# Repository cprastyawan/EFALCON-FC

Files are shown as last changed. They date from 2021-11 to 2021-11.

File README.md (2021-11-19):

# EFALCON-FC

Flight Controller Prototype for X type Quadcopter
Components:
1. STM32F407VGT6 Dev EBox as Microcontroller
2. GY-91: MPU9250 & BMP280 as Sensors
3. Receiver Radio Remote Control (SBUS/PPM/PWM) as Input

Programmings:
1. STM32CubeIDE as IDE
2. STM32 HAL Library as main library
3. CMSIS OS Platform for Real Time Operating System (RTOS)

need info?
ig: CPrastyawan

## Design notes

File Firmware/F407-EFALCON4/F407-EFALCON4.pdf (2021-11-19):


24/06/2021

## F407-EFALCON4 Project Configuration Report

# 1. Description

## 1.1. Project

Project Name | F407-EFALCON4
Board Name | custom
Generated with: | STM32CubeMX 6.2.1
Date | 06/24/2021

## 1.2. MCU

MCU Series | STM32F4
MCU Line | STM32F407/417
MCU name | STM32F407VGTx
MCU Package | LQFP100
MCU Pin number | 100

## 1.3. Core(s) information

Core(s) | Arm Cortex-M4

# 2. Pinout Configuration

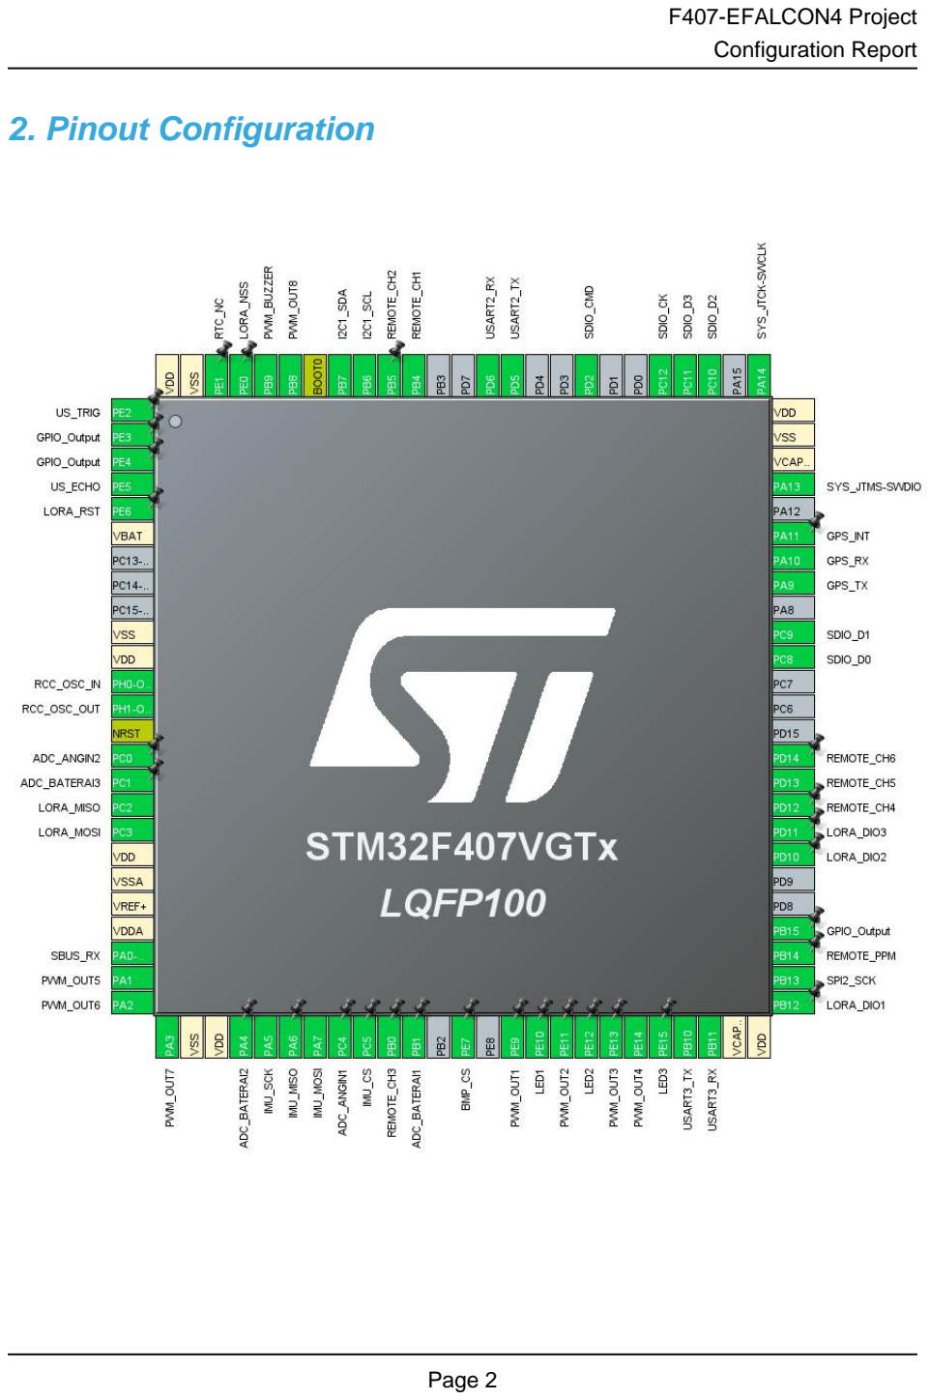
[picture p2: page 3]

# 3. Pins Configuration

Pin Number LQFP100 | Pin Name (function after reset) | Pin Type | Alternate Function(s) | Label
1 | PE2 * | I/O | GPIO_Output | US_TRIG
2 | PE3 * | I/O | GPIO_Output
3 | PE4 * | I/O | GPIO_Output
4 | PE5 | I/O | TIM9_CH1 | US_ECHO
5 | PE6 * | I/O | GPIO_Output | LORA_RST
6 | VBAT | Power
10 | VSS | Power
11 | VDD | Power
12 | PH0-OSC_IN | I/O | RCC_OSC_IN
13 | PH1-OSC_OUT | I/O | RCC_OSC_OUT
14 | NRST | Reset
15 | PC0 | I/O | ADC1_IN10 | ADC_ANGIN2
16 | PC1 | I/O | ADC1_IN11 | ADC_BATERAI3
17 | PC2 | I/O | SPI2_MISO | LORA_MISO
18 | PC3 | I/O | SPI2_MOSI | LORA_MOSI
19 | VDD | Power
20 | VSSA | Power
21 | VREF+ | Power
22 | VDDA | Power
23 | PA0-WKUP | I/O | UART4_TX | SBUS_RX
24 | PA1 | I/O | TIM5_CH2 | PWM_OUT5
25 | PA2 | I/O | TIM5_CH3 | PWM_OUT6
26 | PA3 | I/O | TIM5_CH4 | PWM_OUT7
27 | VSS | Power
28 | VDD | Power
29 | PA4 | I/O | ADC1_IN4 | ADC_BATERAI2
30 | PA5 | I/O | SPI1_SCK | IMU_SCK
31 | PA6 | I/O | SPI1_MISO | IMU_MISO
32 | PA7 | I/O | SPI1_MOSI | IMU_MOSI
33 | PC4 | I/O | ADC1_IN14 | ADC_ANGIN1
34 | PC5 * | I/O | GPIO_Output | IMU_CS
35 | PB0 | I/O | TIM3_CH3 | REMOTE_CH3
36 | PB1 | I/O | ADC1_IN9 | ADC_BATERAI1
38 | PE7 * | I/O | GPIO_Output | BMP_CS
40 | PE9 | I/O | TIM1_CH1 | PWM_OUT1
41 | PE10 * | I/O | GPIO_Output | LED1

Pin Number LQFP100 | Pin Name (function after reset) | Pin Type | Alternate Function(s) | Label
42 | PE11 | I/O | TIM1_CH2 | PWM_OUT2
43 | PE12 * | I/O | GPIO_Output | LED2
44 | PE13 | I/O | TIM1_CH3 | PWM_OUT3
45 | PE14 | I/O | TIM1_CH4 | PWM_OUT4
46 | PE15 * | I/O | GPIO_Output | LED3
47 | PB10 | I/O | USART3_TX
48 | PB11 | I/O | USART3_RX
49 | VCAP_1 | Power
50 | VDD | Power
51 | PB12 * | I/O | GPIO_Output | LORA_DIO1
52 | PB13 | I/O | SPI2_SCK
53 | PB14 | I/O | TIM12_CH1 | REMOTE_PPM
54 | PB15 * | I/O | GPIO_Output
57 | PD10 * | I/O | GPIO_Output | LORA_DIO2
58 | PD11 * | I/O | GPIO_Output | LORA_DIO3
59 | PD12 | I/O | TIM4_CH1 | REMOTE_CH4
60 | PD13 | I/O | TIM4_CH2 | REMOTE_CH5
61 | PD14 | I/O | TIM4_CH3 | REMOTE_CH6
65 | PC8 | I/O | SDIO_D0
66 | PC9 | I/O | SDIO_D1
68 | PA9 | I/O | USART1_TX | GPS_TX
69 | PA10 | I/O | USART1_RX | GPS_RX
70 | PA11 | I/O | GPIO_EXTI11 | GPS_INT
72 | PA13 | I/O | SYS_JTMS-SWDIO
73 | VCAP_2 | Power
74 | VSS | Power
75 | VDD | Power
76 | PA14 | I/O | SYS_JTCK-SWCLK
78 | PC10 | I/O | SDIO_D2
79 | PC11 | I/O | SDIO_D3
80 | PC12 | I/O | SDIO_CK
83 | PD2 | I/O | SDIO_CMD
86 | PD5 | I/O | USART2_TX
87 | PD6 | I/O | USART2_RX
90 | PB4 | I/O | TIM3_CH1 | REMOTE_CH1
91 | PB5 | I/O | TIM3_CH2 | REMOTE_CH2
92 | PB6 | I/O | I2C1_SCL
93 | PB7 | I/O | I2C1_SDA
94 | BOOT0 | Boot

Pin Number LQFP100 | Pin Name (function after reset) | Pin Type | Alternate Function(s) | Label
95 | PB8 | I/O | TIM10_CH1 | PWM_OUT8
96 | PB9 | I/O | TIM11_CH1 | PWM_BUZZER
97 | PE0 * | I/O | GPIO_Output | LORA_NSS
98 | PE1 * | I/O | GPIO_Output | RTC_NC
99 | VSS | Power
100 | VDD | Power

## * The pin is affected with an I/O function

# 4. Clock Tree Configuration

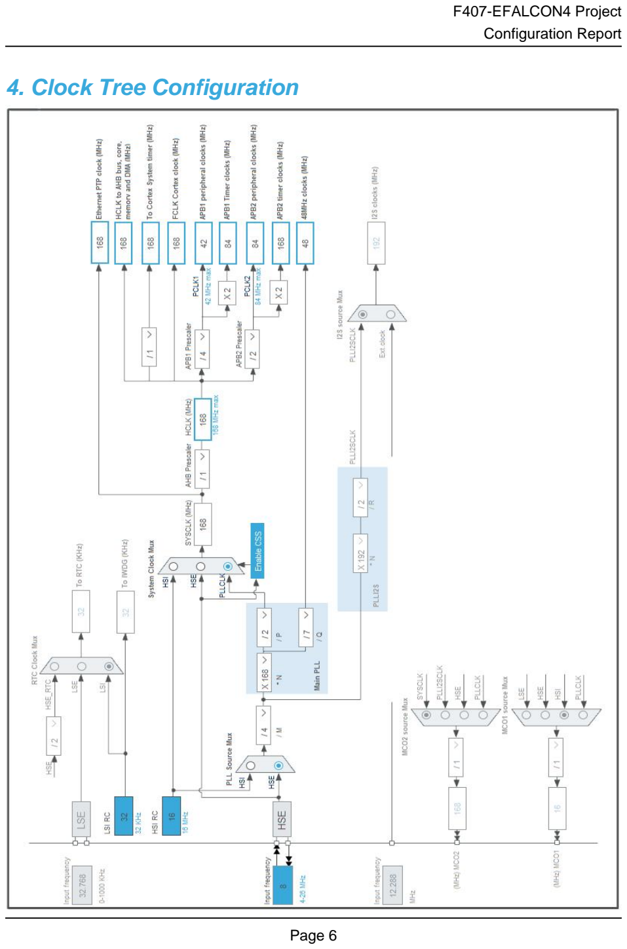
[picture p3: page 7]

# 5. Software Project

## 5.1. Project Settings

Name | Value
Project Name | F407-EFALCON4
Project Folder | C:\Users\LENOVO\git\F407-EFALCON4\F407-EFALCON4
Toolchain / IDE | STM32CubeIDE
Firmware Package Name and Version | STM32Cube FW_F4 V1.26.1
Application Structure | Advanced
Generate Under Root | Yes
Do not generate the main() | No
Minimum Heap Size | 0x200
Minimum Stack Size | 0x400

## 5.2. Code Generation Settings

Name | Value
STM32Cube MCU packages and embedded software | Copy only the necessary library files
Generate peripheral initialization as a pair of '.c/.h' files | No
Backup previously generated files when re-generating | No
Keep User Code when re-generating | Yes
Delete previously generated files when not re-generated | Yes
Set all free pins as analog (to optimize the power consumption) | No
Enable Full Assert | No

## 5.3. Advanced Settings - Generated Function Calls

Rank | Function Name | Peripheral Instance Name
1 | MX_GPIO_Init | GPIO
2 | SystemClock_Config | RCC
3 | MX_I2C1_Init | I2C1
4 | MX_SDIO_SD_Init | SDIO
5 | MX_SPI1_Init | SPI1
6 | MX_SPI2_Init | SPI2
7 | MX_TIM5_Init | TIM5
8 | MX_TIM9_Init | TIM9
9 | MX_TIM10_Init | TIM10
10 | MX_TIM11_Init | TIM11
11 | MX_UART4_Init | UART4

Rank | Function Name | Peripheral Instance Name
12 | MX_USART1_UART_Init | USART1
13 | MX_USART2_UART_Init | USART2
14 | MX_USART3_UART_Init | USART3
15 | MX_ADC1_Init | ADC1
16 | MX_TIM2_Init | TIM2
17 | MX_TIM6_Init | TIM6
18 | MX_TIM12_Init | TIM12
19 | MX_FATFS_Init | FATFS
20 | MX_TIM1_Init | TIM1
21 | MX_TIM3_Init | TIM3
22 | MX_TIM4_Init | TIM4

# 6. Power Consumption Calculator report

## 6.1. Microcontroller Selection

Series | STM32F4
Line | STM32F407/417
MCU | STM32F407VGTx
Datasheet | DS8626_Rev8

## 6.2. Parameter Selection

Temperature | 25
Vdd | 3.3

## 6.3. Battery Selection

Battery | Li-SOCL2(A3400)
Capacity | 3400.0 mAh
Self Discharge | 0.08 %/month
Nominal Voltage | 3.6 V
Max Cont Current | 100.0 mA
Max Pulse Current | 200.0 mA
Cells in series | 1
Cells in parallel | 1

## 6.4. Sequence

Step | Step1 | Step2
Mode | RUN | STOP
Vdd | 3.3 | 3.3
Voltage Source | Battery | Battery
Range | Scale1-High | No Scale
Fetch Type | FLASH | n/a
CPU Frequency | 168 MHz | 0 Hz
Clock Configuration | HSE PLL | Regulator_LP Flash-PwrDwn
Clock Source Frequency | 4 MHz | 0 Hz

### Peripherals

Additional Cons. | 0 mA | 0 mA
Average Current | 46 mA | 280 µA
Duration | 0.1 ms | 0.9 ms
DMIPS | 210.0 | 0.0
Ta Max | 98.47 | 104.96
Category | In DS Table | In DS Table

## 6.5. Results

Sequence Time | 1 ms | Average Current | 4.85 mA
Battery Life | 29 days, 4 hours | Average DMIPS | 210.0 DMIPS

## 6.6. Chart

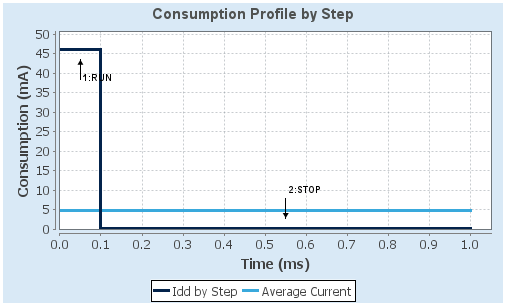
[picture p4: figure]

# 7. Peripherals and Middlewares Configuration

## 7.1. ADC1 mode: IN4 mode: IN9 mode: IN10 mode: IN11 mode: IN14

## 7.1.1. Parameter Settings:

### ADCs_Common_Settings:

Mode | Independent mode

### ADC_Settings:

Clock Prescaler | PCLK2 divided by 4
Resolution | 12 bits (15 ADC Clock cycles)
Data Alignment | Right alignment
Scan Conversion Mode | Disabled
Continuous Conversion Mode | Disabled
Discontinuous Conversion Mode | Disabled
DMA Continuous Requests | Disabled
End Of Conversion Selection | EOC flag at the end of single channel conversion

### ADC_Regular_ConversionMode:

Number Of Conversion | 1
External Trigger Conversion Source | Regular Conversion launched by software
External Trigger Conversion Edge | None
Rank | 1
Channel | Channel 9 *
Sampling Time | 3 Cycles

### ADC_Injected_ConversionMode:

Number Of Conversions | 0

### WatchDog:

Enable Analog WatchDog Mode | false

## 7.2. I2C1 I2C: I2C

## 7.2.1. Parameter Settings:

### Master Features:

I2C Speed Mode | Standard Mode
I2C Clock Speed (Hz) | 100000

### Slave Features:

Clock No Stretch Mode | Disabled
Primary Address Length selection | 7-bit
Dual Address Acknowledged | Disabled
Primary slave address | 0
General Call address detection | Disabled

## 7.3. RCC High Speed Clock (HSE): Crystal/Ceramic Resonator

## 7.3.1. Parameter Settings:

### System Parameters:

VDD voltage (V) | 3.3
Instruction Cache | Enabled
Prefetch Buffer | Enabled
Data Cache | Enabled
Flash Latency(WS) | 5 WS (6 CPU cycle)

### RCC Parameters:

HSI Calibration Value | 16
HSE Startup Timout Value (ms) | 100
LSE Startup Timout Value (ms) | 5000

### Power Parameters:

Power Regulator Voltage Scale | Power Regulator Voltage Scale 1

## 7.4. SDIO Mode: SD 4 bits Wide bus

## 7.4.1. Parameter Settings:

### SDIO parameters:

Clock transition on which the bit capture is made | Rising transition
SDIO Clock divider bypass | Disable
SDIO Clock output enable when the bus is idle | Disable the power save for the clock
SDIO hardware flow control | The hardware control flow is disabled
SDIOCLK clock divide factor | 4 *

## 7.5. SPI1 Mode: Full-Duplex Master

## 7.5.1. Parameter Settings:

### Basic Parameters:

Frame Format | Motorola
Data Size | 8 Bits
First Bit | MSB First

### Clock Parameters:

Prescaler (for Baud Rate) | 32 *
Baud Rate | 2.625 MBits/s *
Clock Polarity (CPOL) | Low
Clock Phase (CPHA) | 1 Edge

### Advanced Parameters:

CRC Calculation | Disabled
NSS Signal Type | Software

## 7.6. SPI2 Mode: Full-Duplex Master

## 7.6.1. Parameter Settings:

### Basic Parameters:

Frame Format | Motorola
Data Size | 8 Bits
First Bit | MSB First

### Clock Parameters:

Prescaler (for Baud Rate) | 2
Baud Rate | 21.0 MBits/s *
Clock Polarity (CPOL) | Low
Clock Phase (CPHA) | 1 Edge

### Advanced Parameters:

CRC Calculation | Disabled
NSS Signal Type | Software

## 7.7. SYS Debug: Serial Wire Timebase Source: TIM7

## 7.8. TIM1 Channel1: PWM Generation CH1 Channel2: PWM Generation CH2 Channel3: PWM Generation CH3 Channel4: PWM Generation CH4

## 7.8.1. Parameter Settings:

### Counter Settings:

Prescaler (PSC - 16 bits value) | 0
Counter Mode | Up
Counter Period (AutoReload Register - 16 bits value ) | 65535
Internal Clock Division (CKD) | No Division
Repetition Counter (RCR - 8 bits value) | 0
auto-reload preload | Disable

### Trigger Output (TRGO) Parameters:

Master/Slave Mode (MSM bit) | Disable (Trigger input effect not delayed)
Trigger Event Selection | Reset (UG bit from TIMx_EGR)

### Break And Dead Time management - BRK Configuration:

BRK State | Disable
BRK Polarity | High

### Break And Dead Time management - Output Configuration:

Automatic Output State | Disable
Off State Selection for Run Mode (OSSR) | Disable
Off State Selection for Idle Mode (OSSI) | Disable
Lock Configuration | Off

### PWM Generation Channel 1:

Mode | PWM mode 1
Pulse (16 bits value) | 0
Output compare preload | Enable
Fast Mode | Disable
CH Polarity | High
CH Idle State | Reset

### PWM Generation Channel 2:

Mode | PWM mode 1

Pulse (16 bits value) | 0
Output compare preload | Enable
Fast Mode | Disable
CH Polarity | High
CH Idle State | Reset

### PWM Generation Channel 3:

Mode | PWM mode 1
Pulse (16 bits value) | 0
Output compare preload | Enable
Fast Mode | Disable
CH Polarity | High
CH Idle State | Reset

### PWM Generation Channel 4:

Mode | PWM mode 1
Pulse (16 bits value) | 0
Output compare preload | Enable
Fast Mode | Disable
CH Polarity | High
CH Idle State | Reset

## 7.9. TIM2 Clock Source : Internal Clock

## 7.9.1. Parameter Settings:

### Counter Settings:

Prescaler (PSC - 16 bits value) | 0
Counter Mode | Up
Counter Period (AutoReload Register - 32 bits value ) | 4294967295
Internal Clock Division (CKD) | No Division
auto-reload preload | Disable

### Trigger Output (TRGO) Parameters:

Master/Slave Mode (MSM bit) | Disable (Trigger input effect not delayed)
Trigger Event Selection | Reset (UG bit from TIMx_EGR)

## 7.10. TIM3 Channel1: Input Capture direct mode Channel2: Input Capture direct mode

## Channel3: Input Capture direct mode

## 7.10.1. Parameter Settings:

### Counter Settings:

Prescaler (PSC - 16 bits value) | 0
Counter Mode | Up
Counter Period (AutoReload Register - 16 bits value ) | 65535
Internal Clock Division (CKD) | No Division
auto-reload preload | Disable

### Trigger Output (TRGO) Parameters:

Master/Slave Mode (MSM bit) | Disable (Trigger input effect not delayed)
Trigger Event Selection | Reset (UG bit from TIMx_EGR)

### Input Capture Channel 1:

Polarity Selection | Rising Edge
IC Selection | Direct
Prescaler Division Ratio | No division
Input Filter (4 bits value) | 0

### Input Capture Channel 2:

Polarity Selection | Rising Edge
IC Selection | Direct
Prescaler Division Ratio | No division
Input Filter (4 bits value) | 0

### Input Capture Channel 3:

Polarity Selection | Rising Edge
IC Selection | Direct
Prescaler Division Ratio | No division
Input Filter (4 bits value) | 0

## 7.11. TIM4 Channel1: Input Capture direct mode Channel2: Input Capture direct mode Channel3: Input Capture direct mode

## 7.11.1. Parameter Settings:

### Counter Settings:

Prescaler (PSC - 16 bits value) | 0
Counter Mode | Up
Counter Period (AutoReload Register - 16 bits value ) | 65535
Internal Clock Division (CKD) | No Division

auto-reload preload | Disable

### Trigger Output (TRGO) Parameters:

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

### Input Capture Channel 1:

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

### Input Capture Channel 2:

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

### Input Capture Channel 3:

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

## 7.12. TIM5 Channel2: PWM Generation CH2 Channel3: PWM Generation CH3 Channel4: PWM Generation CH4

## 7.12.1. Parameter Settings:

### Counter Settings:

Prescaler (PSC - 16 bits value) | 0
Counter Mode | Up
Counter Period (AutoReload Register - 32 bits value ) | 4294967295
Internal Clock Division (CKD) | No Division
auto-reload preload | Disable

### Trigger Output (TRGO) Parameters:

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

### PWM Generation Channel 2:

Mode | PWM mode 1
Pulse (32 bits value) | 0
Output compare preload | Enable

Fast Mode | Disable
CH Polarity | High

### PWM Generation Channel 3:

Mode | PWM mode 1
Pulse (32 bits value) | 0
Output compare preload | Enable
Fast Mode | Disable
CH Polarity | High

### PWM Generation Channel 4:

Mode | PWM mode 1
Pulse (32 bits value) | 0
Output compare preload | Enable
Fast Mode | Disable
CH Polarity | High

## 7.13. TIM6 mode: Activated

## 7.13.1. Parameter Settings:

### Counter Settings:

Prescaler (PSC - 16 bits value) | 84 - 1 *
Counter Mode | Up
Counter Period (AutoReload Register - 16 bits value ) | 10 - 1 *
auto-reload preload | Disable

### Trigger Output (TRGO) Parameters:

Trigger Event Selection | Reset (UG bit from TIMx_EGR)

## 7.14. TIM9 Channel1: Input Capture direct mode Channel2: Input Capture indirect mode

## 7.14.1. Parameter Settings:

### Counter Settings:

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

auto-reload preload | Disable

### Input Capture Channel 1:

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

### Input Capture Channel 2:

Polarity Selection | Rising Edge
IC Selection | Indirect
Prescaler Division Ratio | No division

## 7.15. TIM10 mode: Activated Channel1: PWM Generation CH1

## 7.15.1. Parameter Settings:

### Counter Settings:

Prescaler (PSC - 16 bits value) | 0
Counter Mode | Up
Counter Period (AutoReload Register - 16 bits value ) | 65535
Internal Clock Division (CKD) | No Division
auto-reload preload | Disable

### PWM Generation Channel 1:

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

## 7.16. TIM11 mode: Activated Channel1: PWM Generation CH1

## 7.16.1. Parameter Settings:

### Counter Settings:

Prescaler (PSC - 16 bits value) | 0
Counter Mode | Up

Counter Period (AutoReload Register - 16 bits value ) | 65535
Internal Clock Division (CKD) | No Division
auto-reload preload | Disable

### PWM Generation Channel 1:

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

## 7.17. TIM12 Channel1: Input Capture direct mode Channel2: Input Capture indirect mode

## 7.17.1. Parameter Settings:

### Counter Settings:

Prescaler (PSC - 16 bits value) | 84 - 1 *
Counter Mode | Up
Counter Period (AutoReload Register - 16 bits value ) | 65535
Internal Clock Division (CKD) | No Division
auto-reload preload | Disable

### Input Capture Channel 1:

Polarity Selection | Falling Edge *
IC Selection | Direct
Prescaler Division Ratio | No division
Input Filter (4 bits value) | 0

### Input Capture Channel 2:

Polarity Selection | Rising Edge
IC Selection | Indirect
Prescaler Division Ratio | No division

## 7.18. UART4 Mode: Single Wire (Half-Duplex)

## 7.18.1. Parameter Settings:

### Basic Parameters:

Baud Rate | 115200

Word Length | 8 Bits (including Parity)
Parity | None
Stop Bits | 1

### Advanced Parameters:

Data Direction | Receive Only *
Over Sampling | 16 Samples

## 7.19. USART1 Mode: Asynchronous

## 7.19.1. Parameter Settings:

### Basic Parameters:

Baud Rate | 115200
Word Length | 8 Bits (including Parity)
Parity | None
Stop Bits | 1

### Advanced Parameters:

Data Direction | Receive and Transmit
Over Sampling | 16 Samples

## 7.20. USART2 Mode: Asynchronous

## 7.20.1. Parameter Settings:

### Basic Parameters:

Baud Rate | 115200
Word Length | 8 Bits (including Parity)
Parity | None
Stop Bits | 1

### Advanced Parameters:

Data Direction | Receive and Transmit
Over Sampling | 16 Samples

## 7.21. USART3

## Mode: Asynchronous

## 7.21.1. Parameter Settings:

### Basic Parameters:

Baud Rate | 115200
Word Length | 8 Bits (including Parity)
Parity | None
Stop Bits | 1

### Advanced Parameters:

Data Direction | Receive and Transmit
Over Sampling | 16 Samples

## 7.22. ARM.CMSIS.5.6.0 mode: CMSISJjDSP

## 7.23. FATFS mode: SD Card

## 7.23.1. Set Defines:

### Version:

FATFS version | R0.12c

### Function Parameters:

FS_READONLY (Read-only mode) | Disabled
FS_MINIMIZE (Minimization level) | Disabled
USE_STRFUNC (String functions) | Enabled with LF -> CRLF conversion
USE_FIND (Find functions) | Disabled
USE_MKFS (Make filesystem function) | Enabled
USE_FASTSEEK (Fast seek function) | Enabled
USE_EXPAND (Use f_expand function) | Disabled
USE_CHMOD (Change attributes function) | Disabled
USE_LABEL (Volume label functions) | Disabled
USE_FORWARD (Forward function) | Disabled

### Locale and Namespace Parameters:

CODE_PAGE (Code page on target) | Latin 1
USE_LFN (Use Long Filename) | Disabled
MAX_LFN (Max Long Filename) | 255
LFN_UNICODE (Enable Unicode) | ANSI/OEM
STRF_ENCODE (Character encoding) | UTF-8
FS_RPATH (Relative Path) | Disabled

### Physical Drive Parameters:

VOLUMES (Logical drives) | 1
MAX_SS (Maximum Sector Size) | 512
MIN_SS (Minimum Sector Size) | 512
MULTI_PARTITION (Volume partitions feature) | Disabled
USE_TRIM (Erase feature) | Disabled
FS_NOFSINFO (Force full FAT scan) | 0

### System Parameters:

FS_TINY (Tiny mode) | Disabled
FS_EXFAT (Support of exFAT file system) | Disabled
FS_NORTC (Timestamp feature) | Dynamic timestamp
FS_REENTRANT (Re-Entrancy) | Enabled
FS_TIMEOUT (Timeout ticks) | 1000
USE_MUTEX | Disabled
SYNC_t (O/S sync object) | osSemaphoreId_t
FS_LOCK (Number of files opened simultaneously) | 2

## 7.23.2. Advanced Settings:

### SDIO/SDMMC:

SDIO instance | SDIO
Use dma template | Enabled
BSP code for SD | Generic

## 7.24. FREERTOS Interface: CMSIS_V2

## 7.24.1. Config parameters:

### API:

FreeRTOS API | CMSIS v2

### Versions:

FreeRTOS version | 10.3.1
CMSIS-RTOS version | 2.00

### MPU/FPU:

ENABLE_MPU | Disabled
ENABLE_FPU | Enabled *

### Kernel settings:

USE_PREEMPTION | Enabled
CPU_CLOCK_HZ | SystemCoreClock

TICK_RATE_HZ | 1000
MAX_PRIORITIES | 56
MINIMAL_STACK_SIZE | 512 *
MAX_TASK_NAME_LEN | 16
USE_16_BIT_TICKS | Disabled
IDLE_SHOULD_YIELD | Enabled
USE_MUTEXES | Enabled
USE_RECURSIVE_MUTEXES | Enabled
USE_COUNTING_SEMAPHORES | Enabled
QUEUE_REGISTRY_SIZE | 8
USE_APPLICATION_TASK_TAG | Disabled
ENABLE_BACKWARD_COMPATIBILITY | Enabled
USE_PORT_OPTIMISED_TASK_SELECTION | Disabled
USE_TICKLESS_IDLE | Disabled
USE_TASK_NOTIFICATIONS | Enabled
RECORD_STACK_HIGH_ADDRESS | Disabled

### Memory management settings:

Memory Allocation | Dynamic / Static
TOTAL_HEAP_SIZE | 15360
Memory Management scheme | heap_4

### Hook function related definitions:

USE_IDLE_HOOK | Disabled
USE_TICK_HOOK | Disabled
USE_MALLOC_FAILED_HOOK | Disabled
USE_DAEMON_TASK_STARTUP_HOOK | Disabled
CHECK_FOR_STACK_OVERFLOW | Disabled

### Run time and task stats gathering related definitions:

GENERATE_RUN_TIME_STATS | Disabled
USE_TRACE_FACILITY | Enabled
USE_STATS_FORMATTING_FUNCTIONS | Disabled

### Co-routine related definitions:

USE_CO_ROUTINES | Disabled
MAX_CO_ROUTINE_PRIORITIES | 2

### Software timer definitions:

USE_TIMERS | Enabled
TIMER_TASK_PRIORITY | 2
TIMER_QUEUE_LENGTH | 10
TIMER_TASK_STACK_DEPTH | 1024

### Interrupt nesting behaviour configuration:

LIBRARY_LOWEST_INTERRUPT_PRIORITY | 15
LIBRARY_MAX_SYSCALL_INTERRUPT_PRIORITY | 5

### Added with 10.2.1 support:

MESSAGE_BUFFER_LENGTH_TYPE | size_t
USE_POSIX_ERRNO | Disabled

### CMSIS-RTOS V2 flags:

USE_OS2_THREAD_SUSPEND_RESUME | Enabled
USE_OS2_THREAD_ENUMERATE | Enabled
USE_OS2_EVENTFLAGS_FROM_ISR | Enabled
USE_OS2_THREAD_FLAGS | Enabled
USE_OS2_TIMER | Enabled
USE_OS2_MUTEX | Enabled

## 7.24.2. Include parameters:

### Include definitions:

vTaskPrioritySet | Enabled
uxTaskPriorityGet | Enabled
vTaskDelete | Enabled
vTaskCleanUpResources | Disabled
vTaskSuspend | Enabled
vTaskDelayUntil | Enabled
vTaskDelay | Enabled
xTaskGetSchedulerState | Enabled
xTaskResumeFromISR | Enabled
xQueueGetMutexHolder | Enabled
xSemaphoreGetMutexHolder | Disabled
pcTaskGetTaskName | Disabled
uxTaskGetStackHighWaterMark | Enabled
xTaskGetCurrentTaskHandle | Enabled
eTaskGetState | Enabled
xEventGroupSetBitFromISR | Disabled
xTimerPendFunctionCall | Enabled
xTaskAbortDelay | Disabled
xTaskGetHandle | Disabled
uxTaskGetStackHighWaterMark2 | Disabled

## 7.24.3. Advanced settings:

### Newlib settings (see parameter description first):

USE_NEWLIB_REENTRANT | Disabled

### Project settings (see parameter description first):

Use FW pack heap file | Enabled

### * User modified value

# 8. System Configuration

## 8.1. GPIO configuration

IP | Pin | Signal | GPIO mode | GPIO pull/up pull down

## Max Speed

## User Label

ADC1 | PC0 | ADC1_IN10 | Analog mode | No pull-up and no pull-down | n/a | ADC_ANGIN2
| PC1 | ADC1_IN11 | Analog mode | No pull-up and no pull-down | n/a | ADC_BATERAI3
| PA4 | ADC1_IN4 | Analog mode | No pull-up and no pull-down | n/a | ADC_BATERAI2
| PC4 | ADC1_IN14 | Analog mode | No pull-up and no pull-down | n/a | ADC_ANGIN1
| PB1 | ADC1_IN9 | Analog mode | No pull-up and no pull-down | n/a | ADC_BATERAI1
I2C1 | PB6 | I2C1_SCL | Alternate Function Open Drain | Pull-up | Very High
*
| PB7 | I2C1_SDA | Alternate Function Open Drain | Pull-up | Very High
*
RCC | PH0- OSC_IN | RCC_OSC_IN | n/a | n/a | n/a
| PH1- OSC_OUT | RCC_OSC_OUT | n/a | n/a | n/a
SDIO | PC8 | SDIO_D0 | Alternate Function Push Pull | No pull-up and no pull-down | Very High
| PC9 | SDIO_D1 | Alternate Function Push Pull | No pull-up and no pull-down | Very High
| PC10 | SDIO_D2 | Alternate Function Push Pull | No pull-up and no pull-down | Very High
| PC11 | SDIO_D3 | Alternate Function Push Pull | No pull-up and no pull-down | Very High
| PC12 | SDIO_CK | Alternate Function Push Pull | No pull-up and no pull-down | Very High
| PD2 | SDIO_CMD | Alternate Function Push Pull | No pull-up and no pull-down | Very High
SPI1 | PA5 | SPI1_SCK | Alternate Function Push Pull | No pull-up and no pull-down | Very High
*
| | | | | | IMU_SCK
| PA6 | SPI1_MISO | Alternate Function Push Pull | No pull-up and no pull-down | Very High
*
| | | | | | IMU_MISO
| PA7 | SPI1_MOSI | Alternate Function Push Pull | No pull-up and no pull-down | Very High
*
| | | | | | IMU_MOSI
SPI2 | PC2 | SPI2_MISO | Alternate Function Push Pull | No pull-up and no pull-down | Very High
*
| | | | | | LORA_MISO
| PC3 | SPI2_MOSI | Alternate Function Push Pull | No pull-up and no pull-down | Very High
*
| | | | | | LORA_MOSI
| PB13 | SPI2_SCK | Alternate Function Push Pull | No pull-up and no pull-down | Very High
*
SYS | PA13 | SYS_JTMS- SWDIO | n/a | n/a | n/a
| PA14 | SYS_JTCK- SWCLK | n/a | n/a | n/a

IP | Pin | Signal | GPIO mode | GPIO pull/up pull down

## Max Speed

## User Label

TIM1 | PE9 | TIM1_CH1 | Alternate Function Push Pull | No pull-up and no pull-down | Low | PWM_OUT1
| PE11 | TIM1_CH2 | Alternate Function Push Pull | No pull-up and no pull-down | Low | PWM_OUT2
| PE13 | TIM1_CH3 | Alternate Function Push Pull | No pull-up and no pull-down | Low | PWM_OUT3
| PE14 | TIM1_CH4 | Alternate Function Push Pull | No pull-up and no pull-down | Low | PWM_OUT4
TIM3 | PB0 | TIM3_CH3 | Alternate Function Push Pull | No pull-up and no pull-down | Low | REMOTE_CH3
| PB4 | TIM3_CH1 | Alternate Function Push Pull | No pull-up and no pull-down | Low | REMOTE_CH1
| PB5 | TIM3_CH2 | Alternate Function Push Pull | No pull-up and no pull-down | Low | REMOTE_CH2
TIM4 | PD12 | TIM4_CH1 | Alternate Function Push Pull | No pull-up and no pull-down | Low | REMOTE_CH4
| PD13 | TIM4_CH2 | Alternate Function Push Pull | No pull-up and no pull-down | Low | REMOTE_CH5
| PD14 | TIM4_CH3 | Alternate Function Push Pull | No pull-up and no pull-down | Low | REMOTE_CH6
TIM5 | PA1 | TIM5_CH2 | Alternate Function Push Pull | No pull-up and no pull-down | Low | PWM_OUT5
| PA2 | TIM5_CH3 | Alternate Function Push Pull | No pull-up and no pull-down | Low | PWM_OUT6
| PA3 | TIM5_CH4 | Alternate Function Push Pull | No pull-up and no pull-down | Low | PWM_OUT7
TIM9 | PE5 | TIM9_CH1 | Alternate Function Push Pull | No pull-up and no pull-down | Low | US_ECHO
TIM10 | PB8 | TIM10_CH1 | Alternate Function Push Pull | No pull-up and no pull-down | Low | PWM_OUT8
TIM11 | PB9 | TIM11_CH1 | Alternate Function Push Pull | No pull-up and no pull-down | Low | PWM_BUZZER
TIM12 | PB14 | TIM12_CH1 | Alternate Function Push Pull | No pull-up and no pull-down | Low | REMOTE_PPM
UART4 | PA0-WKUP | UART4_TX | Alternate Function Open Drain | Pull-up | Very High
*
| | | | | | SBUS_RX
USART1 | PA9 | USART1_TX | Alternate Function Push Pull | No pull-up and no pull-down | Very High
*
| | | | | | GPS_TX
| PA10 | USART1_RX | Alternate Function Push Pull | No pull-up and no pull-down | Very High
*
| | | | | | GPS_RX
USART2 | PD5 | USART2_TX | Alternate Function Push Pull | No pull-up and no pull-down | Very High
*
| PD6 | USART2_RX | Alternate Function Push Pull | No pull-up and no pull-down | Very High
*
USART3 | PB10 | USART3_TX | Alternate Function Push Pull | No pull-up and no pull-down | Very High
*
| PB11 | USART3_RX | Alternate Function Push Pull | No pull-up and no pull-down | Very High
*
GPIO | PE2 | GPIO_Output | Output Push Pull | No pull-up and no pull-down | Low | US_TRIG
| PE3 | GPIO_Output | Output Push Pull | No pull-up and no pull-down | Low
| PE4 | GPIO_Output | Output Push Pull | No pull-up and no pull-down | Low
| PE6 | GPIO_Output | Output Push Pull | No pull-up and no pull-down | Low | LORA_RST
| PC5 | GPIO_Output | Output Push Pull | No pull-up and no pull-down | Low | IMU_CS
| PE7 | GPIO_Output | Output Push Pull | No pull-up and no pull-down | Low | BMP_CS
| PE10 | GPIO_Output | Output Push Pull | No pull-up and no pull-down | Low | LED1
| PE12 | GPIO_Output | Output Push Pull | No pull-up and no pull-down | Low | LED2

IP | Pin | Signal | GPIO mode | GPIO pull/up pull down | Max Speed | User Label
| PE15 | GPIO_Output | Output Push Pull | No pull-up and no pull-down | Low | LED3
| PB12 | GPIO_Output | Output Push Pull | No pull-up and no pull-down | Low | LORA_DIO1
| PB15 | GPIO_Output | Output Push Pull | No pull-up and no pull-down | Low
| PD10 | GPIO_Output | Output Push Pull | No pull-up and no pull-down | Low | LORA_DIO2
| PD11 | GPIO_Output | Output Push Pull | No pull-up and no pull-down | Low | LORA_DIO3
| PA11 | GPIO_EXTI11 | External Interrupt Mode with Rising edge trigger detection | No pull-up and no pull-down | n/a | GPS_INT
| PE0 | GPIO_Output | Output Push Pull | No pull-up and no pull-down | Low | LORA_NSS
| PE1 | GPIO_Output | Output Push Pull | No pull-up and no pull-down | Low | RTC_NC

## 8.2. DMA configuration

## nothing configured in DMA service

## 8.3. NVIC configuration

## 8.3.1. NVIC

Interrupt Table | Enable | Preenmption Priority | SubPriority
Non maskable interrupt | true | 0 | 0
Hard fault interrupt | true | 0 | 0
Memory management fault | true | 0 | 0
Pre-fetch fault, memory access fault | true | 0 | 0
Undefined instruction or illegal state | true | 0 | 0
System service call via SWI instruction | true | 0 | 0
Debug monitor | true | 0 | 0
Pendable request for system service | true | 15 | 0
System tick timer | true | 15 | 0
USART2 global interrupt | true | 5 | 0
TIM8 break interrupt and TIM12 global interrupt | true | 5 | 0
TIM6 global interrupt, DAC1 and DAC2 underrun error interrupts | true | 5 | 0
TIM7 global interrupt | true | 0 | 0
PVD interrupt through EXTI line 16 | unused
Flash global interrupt | unused
RCC global interrupt | unused
ADC1, ADC2 and ADC3 global interrupts | unused
TIM1 break interrupt and TIM9 global interrupt | unused
TIM1 update interrupt and TIM10 global interrupt | unused
TIM1 trigger and commutation interrupts and TIM11 global interrupt | unused
TIM1 capture compare interrupt | unused
TIM2 global interrupt | unused
TIM3 global interrupt | unused
TIM4 global interrupt | unused
I2C1 event interrupt | unused
I2C1 error interrupt | unused
SPI1 global interrupt | unused
SPI2 global interrupt | unused
USART1 global interrupt | unused
USART3 global interrupt | unused
EXTI line[15:10] interrupts | unused
SDIO global interrupt | unused
TIM5 global interrupt | unused
UART4 global interrupt | unused
FPU global interrupt | unused

## 8.3.2. NVIC Code generation

Enabled interrupt Table | Select for init sequence ordering | Generate IRQ handler | Call HAL handler
Non maskable interrupt | false | true | false
Hard fault interrupt | false | true | false
Memory management fault | false | true | false
Pre-fetch fault, memory access fault | false | true | false
Undefined instruction or illegal state | false | true | false
System service call via SWI instruction | false | false | false
Debug monitor | false | true | false
Pendable request for system service | false | false | false
System tick timer | false | false | true
USART2 global interrupt | false | true | true
TIM8 break interrupt and TIM12 global interrupt | true | true | true
TIM6 global interrupt, DAC1 and DAC2 underrun error interrupts | true | true | true
TIM7 global interrupt | false | true | true

### * User modified value

# 9. System Views

## 9.1. Category view

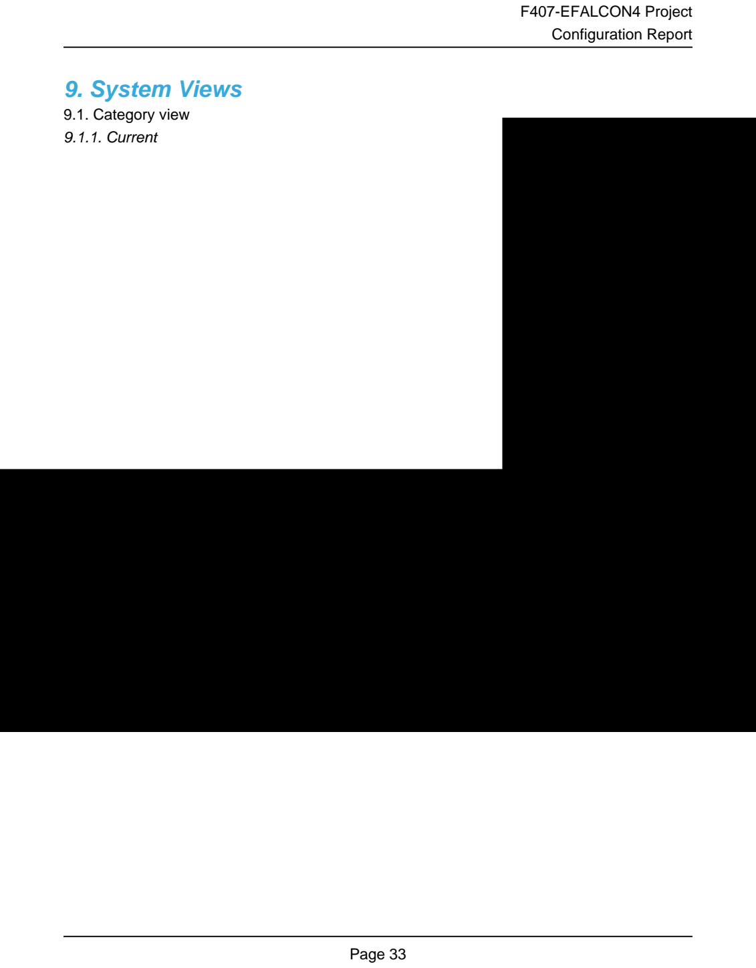
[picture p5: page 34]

## 9.1.1. Current

# 10. Software Pack Report

## 10.1. Software Pack selected

Vendor | Name | Version | Component
ARM | CMSIS | 5.6.0 | Class : CMSIS Group : CORE Version : 5.3.0 Class : CMSIS Group : DSP Variant : Library Version : 1.7.0

# 11. Docs & Resources

Type | Link
Datasheet | http://www.st.com/resource/en/datasheet/DM00037051.pdf
Reference manual | http://www.st.com/resource/en/reference_manual/DM00031020.pdf
Programming manual | http://www.st.com/resource/en/programming_manual/DM00046982.pdf
Errata sheet | http://www.st.com/resource/en/errata_sheet/DM00037591.pdf
Application note | http://www.st.com/resource/en/application_note/CD00167594.pdf
Application note | http://www.st.com/resource/en/application_note/CD00211314.pdf
Application note | http://www.st.com/resource/en/application_note/CD00249778.pdf
Application note | http://www.st.com/resource/en/application_note/CD00259245.pdf
Application note | http://www.st.com/resource/en/application_note/CD00264321.pdf
Application note | http://www.st.com/resource/en/application_note/CD00264342.pdf
Application note | http://www.st.com/resource/en/application_note/CD00264379.pdf
Application note | http://www.st.com/resource/en/application_note/DM00024853.pdf
Application note | http://www.st.com/resource/en/application_note/DM00025071.pdf
Application note | http://www.st.com/resource/en/application_note/DM00040802.pdf
Application note | http://www.st.com/resource/en/application_note/DM00040808.pdf
Application note | http://www.st.com/resource/en/application_note/DM00042534.pdf
Application note | http://www.st.com/resource/en/application_note/DM00046011.pdf
Application note | http://www.st.com/resource/en/application_note/DM00050879.pdf
Application note | http://www.st.com/resource/en/application_note/DM00072315.pdf
Application note | http://www.st.com/resource/en/application_note/DM00073742.pdf
Application note | http://www.st.com/resource/en/application_note/DM00073853.pdf
Application note | http://www.st.com/resource/en/application_note/DM00080497.pdf
Application note | http://www.st.com/resource/en/application_note/DM00081379.pdf
Application note | http://www.st.com/resource/en/application_note/DM00115714.pdf
Application note | http://www.st.com/resource/en/application_note/DM00123028.pdf

Application note | http://www.st.com/resource/en/application_note/DM00129215.pdf
Application note | http://www.st.com/resource/en/application_note/DM00154959.pdf
Application note | http://www.st.com/resource/en/application_note/DM00160482.pdf
Application note | http://www.st.com/resource/en/application_note/DM00213525.pdf
Application note | http://www.st.com/resource/en/application_note/DM00220769.pdf
Application note | http://www.st.com/resource/en/application_note/DM00257177.pdf
Application note | http://www.st.com/resource/en/application_note/DM00272912.pdf
Application note | http://www.st.com/resource/en/application_note/DM00226326.pdf
Application note | http://www.st.com/resource/en/application_note/DM00236305.pdf
Application note | http://www.st.com/resource/en/application_note/DM00263732.pdf
Application note | http://www.st.com/resource/en/application_note/DM00281138.pdf
Application note | http://www.st.com/resource/en/application_note/DM00296349.pdf
Application note | http://www.st.com/resource/en/application_note/DM00327191.pdf
Application note | http://www.st.com/resource/en/application_note/DM00354244.pdf
Application note | http://www.st.com/resource/en/application_note/DM00373474.pdf
Application note | http://www.st.com/resource/en/application_note/DM00315319.pdf
Application note | http://www.st.com/resource/en/application_note/DM00380469.pdf
Application note | http://www.st.com/resource/en/application_note/DM00395696.pdf
Application note | http://www.st.com/resource/en/application_note/DM00431633.pdf
Application note | http://www.st.com/resource/en/application_note/DM00493651.pdf
Application note | http://www.st.com/resource/en/application_note/DM00536349.pdf
Application note | http://www.st.com/resource/en/application_note/DM00725181.pdf

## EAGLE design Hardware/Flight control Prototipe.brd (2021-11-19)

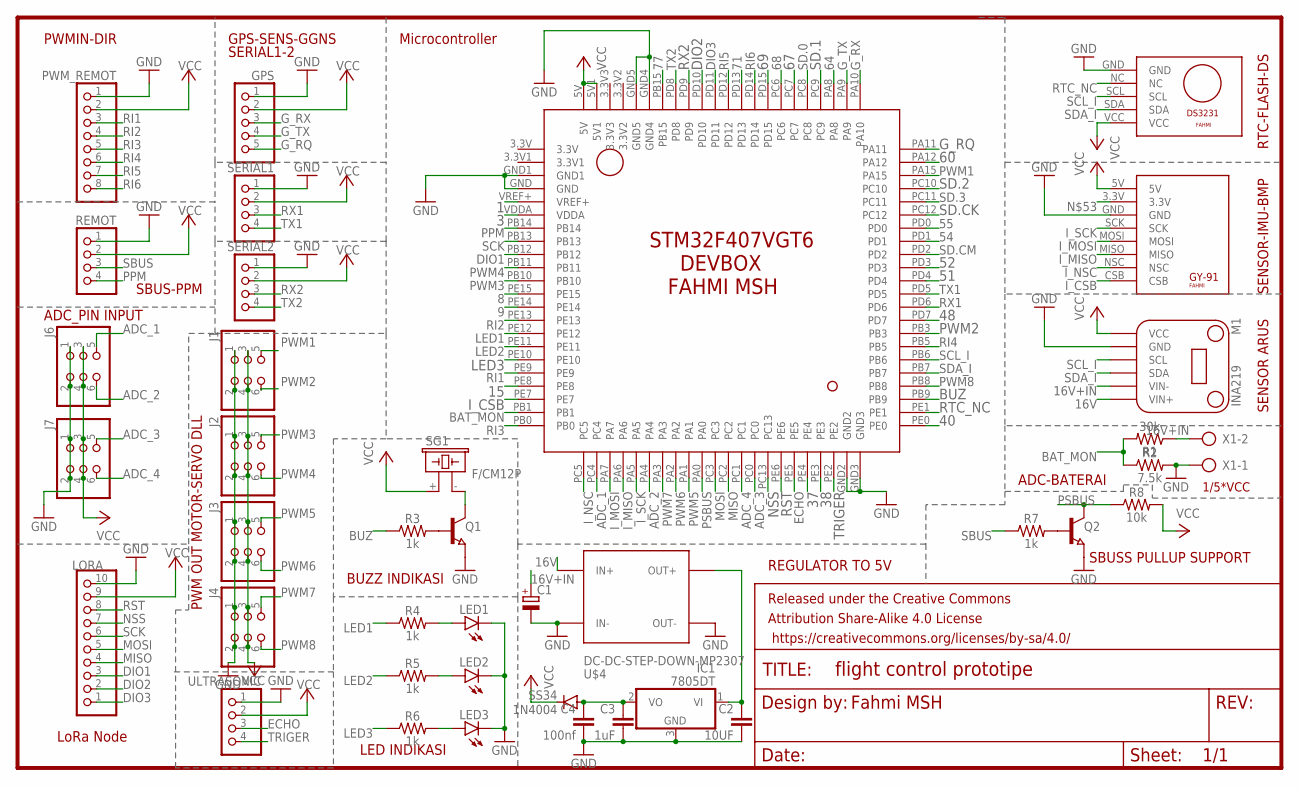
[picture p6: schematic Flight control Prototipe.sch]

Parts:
C1: CPOL-EUE3.5-8; E3,5-8
C2: 10UF; C0805K
C3: 1uF; C0805K
C4: 100nf; C0805K
FRAME1: FRAME-LEDGER; CREATIVE_COMMONS
GPS: PINHD-1X5; 1X05
IC1: 7805DT; TO252
J1, J2, J3, J4, J6, J7: PINHD-2X3; 2X03
LED1, LED2, LED3: LED3MM
LORA: PINHD-1X10; 1X10
M1: INA219
PWM_REMOT: PINHD-1X8; 1X08
Q1, Q2: NPN-TRANSISTOR_SOT23; SOT23
R1: 30k; 0805
R2: 7.5k; 0805
R3, R4, R5, R6, R7: 1k; 0805
R8: 10k; 0805
REMOT: PINHD-1X4; 1X04
SERIAL1, SERIAL2: PINHD-1X4; 1X04
SG1: F/CM12P
SS34: 1N4004; DO41-10
U$1: STM32F4DEVBOX
U$2: GY-91
U$3: DS3231MINI
U$4: DC-DC-STEP-DOWN-MP2307
ULTRASONIC: PINHD-1X4; 1X04
X1: AK500/2

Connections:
1: U$1.VREF+
3: U$1.VDDA
8: U$1.PE15
9: U$1.PE14
15: U$1.PE8
16V: M1.VIN+, U$4.IN+
16V+IN: C1.+, M1.VIN-, R1.1, X1.2
37: U$1.PE4
38: U$1.PE3
40: U$1.PE0
48: U$1.PD7
51: U$1.PD4
52: U$1.PD3
54: U$1.PD1
55: U$1.PD0
60: U$1.PA12
64: U$1.PA8
67: U$1.PC7
68: U$1.PC6
69: U$1.PD15
71: U$1.PD13
77: U$1.PB15
ADC_1: J6.5, U$1.PC4
ADC_2: J6.6, U$1.PA4
ADC_3: J7.5, U$1.PC0
ADC_4: J7.6, U$1.PC1
BAT_MON: R1.2, R2.1, U$1.PB1
BUZ: R3.1, U$1.PB9
DIO1: LORA.3, U$1.PB12
DIO2: LORA.2, U$1.PD10
DIO3: LORA.1, U$1.PD11
ECHO: U$1.PE5, ULTRASONIC.3
GND: C1.-, C2.2, C3.2, C4.2, GPS.1, IC1.3 (GND), J1.1, J1.2, J2.1, J2.2, J3.1, J3.2, J4.1, J4.2, J6.1, J6.2, J7.1, J7.2, LED1.K (C), LED2.K (C), LED3.K (C), LORA.10, M1.GND, PWM_REMOT.1, Q1.2 (E), Q2.2 (E), R2.2, REMOT.1, SERIAL1.1, SERIAL2.1, U$1.GND, U$1.GND1, U$1.GND2, U$1.GND3, U$1.GND4, U$1.GND5, U$2.GND, U$3.GND, U$4.IN-, U$4.OUT-, ULTRASONIC.1, X1.1
G_RQ: GPS.5, U$1.PA11
G_RX: GPS.3, U$1.PA10
G_TX: GPS.4, U$1.PA9
I_CSB: U$1.PE7, U$2.CSB
I_MISO: U$1.PA6, U$2.MISO
I_MOSI: U$1.PA7, U$2.MOSI
I_NSC: U$1.PC5, U$2.NSC
I_SCK: U$1.PA5, U$2.SCK
LED1: R4.1, U$1.PE12
LED2: R5.1, U$1.PE11
LED3: R6.1, U$1.PE10
MISO: LORA.4, U$1.PC2
MOSI: LORA.5, U$1.PC3
unnamed: Q1.1 (B), R3.2
unnamed: Q1.3 (C), SG1.- (2)
unnamed: LED1.A, R4.2
unnamed: LED2.A, R5.2
unnamed: LED3.A, R6.2
unnamed: C2.1, IC1.1 (VI), U$4.OUT+
unnamed: C3.1, C4.1, IC1.2 (VO), SS34.A
unnamed: Q2.1 (B), R7.2
NSS: LORA.7, U$1.PC13
PPM: REMOT.4, U$1.PB14
PSBUS: Q2.3 (C), R8.1, U$1.PA0
PWM1: J1.5, U$1.PA15
PWM2: J1.6, U$1.PB3
PWM3: J2.5, U$1.PB10
PWM4: J2.6, U$1.PB11
PWM5: J3.5, U$1.PA1
PWM6: J3.6, U$1.PA2
PWM7: J4.5, U$1.PA3
PWM8: J4.6, U$1.PB8
RI1: PWM_REMOT.3, U$1.PE9
RI2: PWM_REMOT.4, U$1.PE13
RI3: PWM_REMOT.5, U$1.PB0
RI4: PWM_REMOT.6, U$1.PB5
RI5: PWM_REMOT.7, U$1.PD12
RI6: PWM_REMOT.8, U$1.PD14
RST: LORA.8, U$1.PE6
RTC_NC: U$1.PE1, U$3.NC
RX1: SERIAL1.3, U$1.PD6
RX2: SERIAL2.3, U$1.PD9
SBUS: R7.1, REMOT.3
SCK: LORA.6, U$1.PB13
SCL_I: M1.SCL, U$1.PB6, U$3.SCL
SD.0: U$1.PC8
SD.1: U$1.PC9
SD.2: U$1.PC10
SD.3: U$1.PC11
SD.CK: U$1.PC12
SD.CM: U$1.PD2
SDA_I: M1.SDA, U$1.PB7, U$3.SDA
TRIGER: U$1.PE2, ULTRASONIC.4
TX1: SERIAL1.4, U$1.PD5
TX2: SERIAL2.4, U$1.PD8
VCC: GPS.2, J1.3, J1.4, J2.3, J2.4, J3.3, J3.4, J4.3, J4.4, J6.3, J6.4, J7.3, J7.4, LORA.9, M1.VCC, PWM_REMOT.2, R8.2, REMOT.2, SERIAL1.2, SERIAL2.2, SG1.+ (1), SS34.C, U$1.5V, U$1.5V1, U$2.5V, U$3.VCC, ULTRASONIC.2

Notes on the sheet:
1/5*VCC
Microcontroller
LoRa Node
ADC_PIN INPUT
SBUS-PPM
PWMIN-DIR
GPS-SENS-GGNS
PWM OUT MOTOR-SERVO DLL
LED INDIKASI
BUZZ INDIKASI
SERIAL1-2
REGULATOR TO 5V
SBUSS PULLUP SUPPORT
ADC-BATERAI
SENSOR ARUS
SENSOR-IMU-BMP
RTC-FLASH-DS
Fahmi MSH

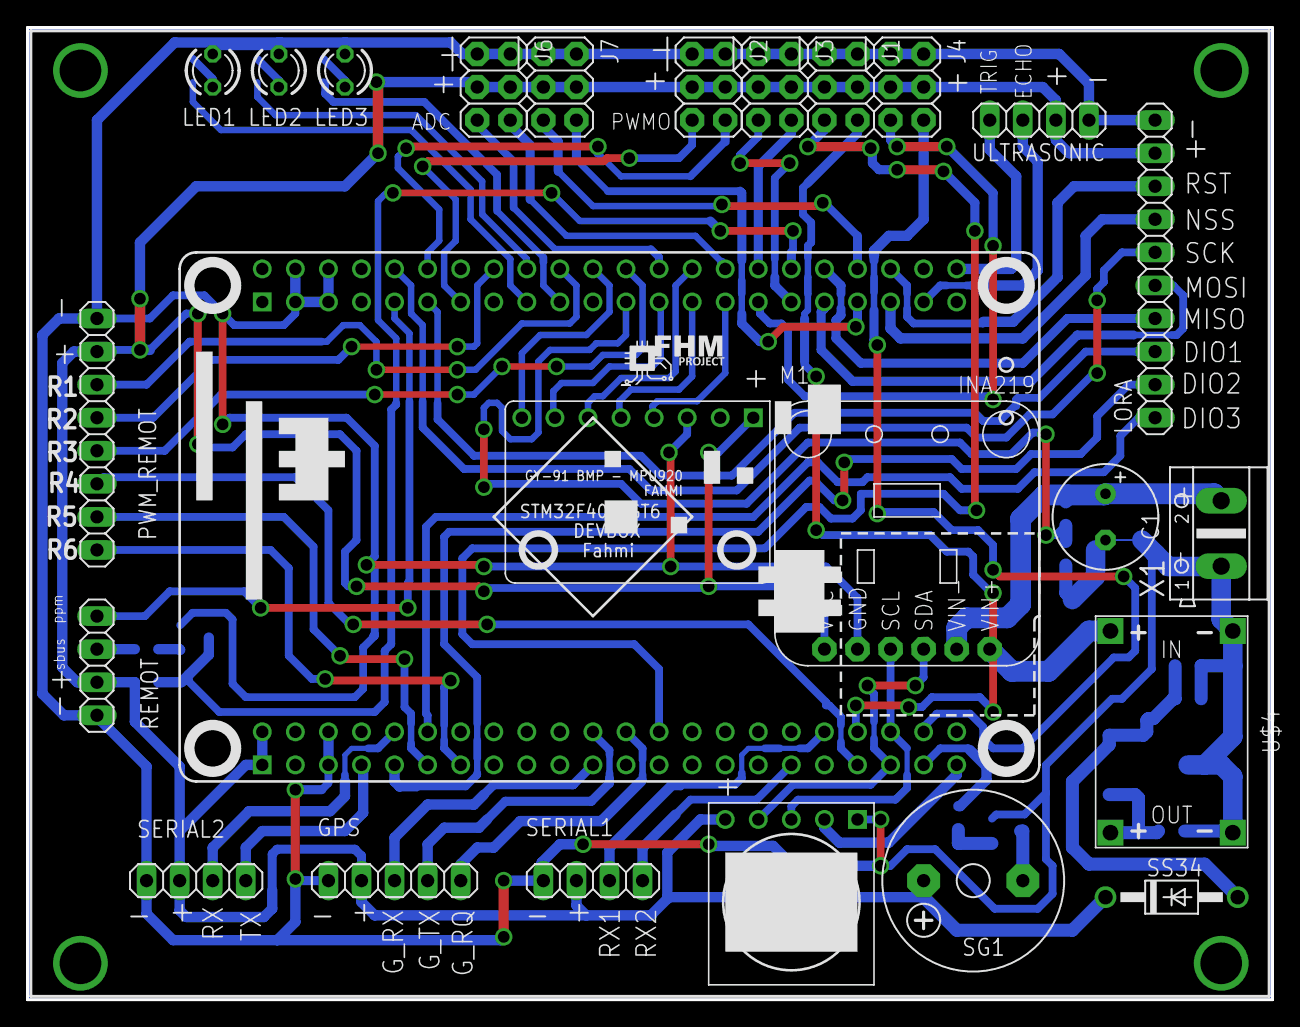
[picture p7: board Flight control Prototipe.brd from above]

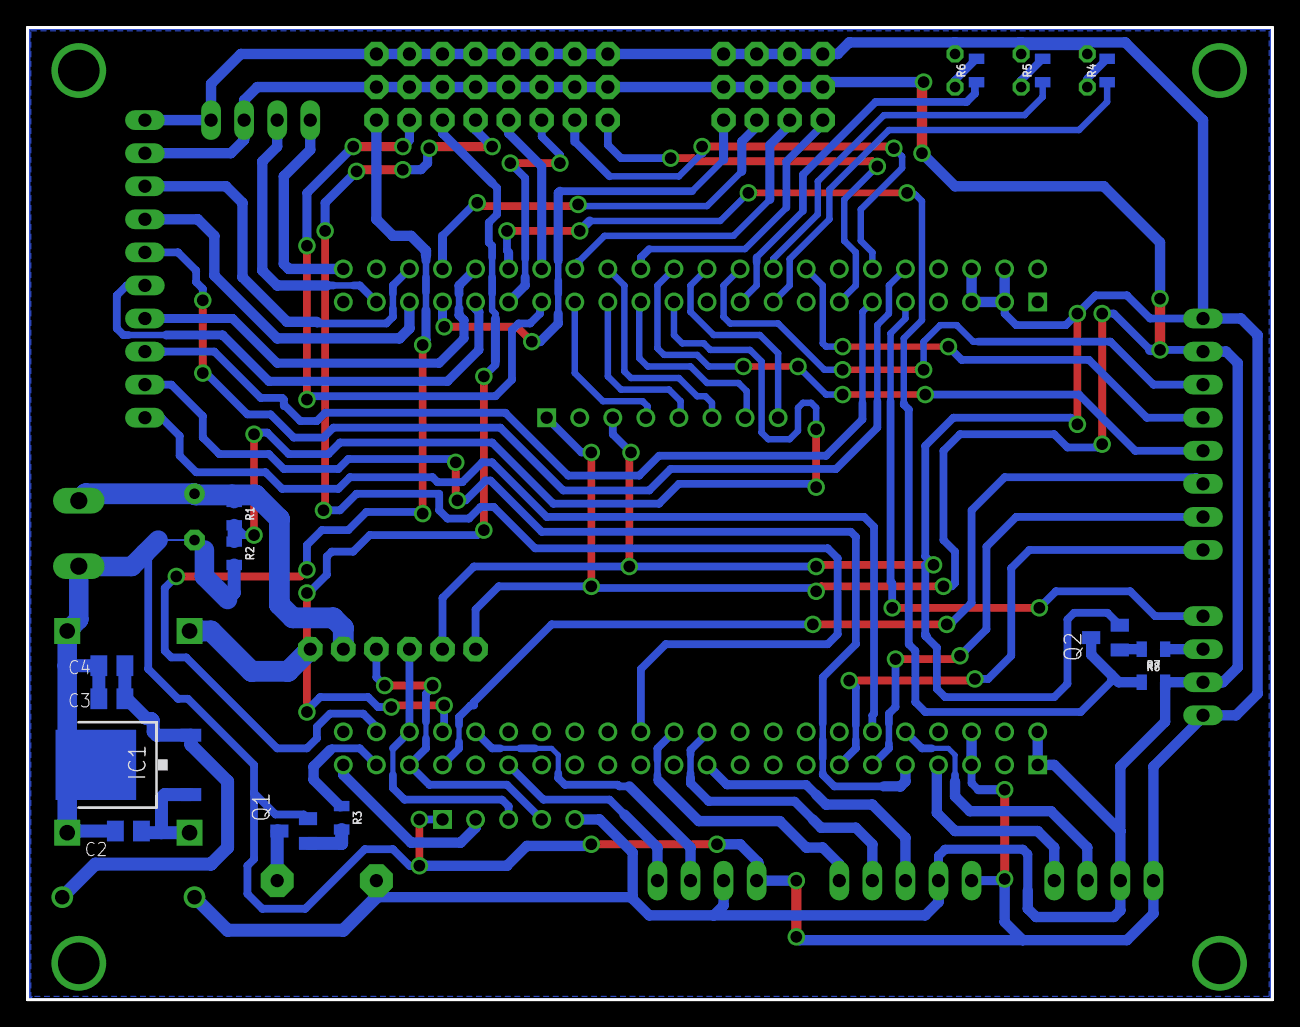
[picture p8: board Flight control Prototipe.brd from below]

Board: 2 copper layers, 95.6 x 74.7 mm, 40 parts (14 on the bottom side), 63 nets.

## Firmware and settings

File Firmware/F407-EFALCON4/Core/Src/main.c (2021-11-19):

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
/* Includes ------------------------------------------------------------------*/
#include "main.h"
#include "cmsis_os.h"
#include "fatfs.h"

/* USER CODE BEGIN Includes */
#include <stdio.h>
#include <string.h>
#include <stdlib.h>
#include <stdbool.h>

#include "MPU9250.h"
#include "IMU.h"
#include "Fusion.h"
#include "bmp2.h"
#include "retarget.h"
#include "bmp2_app.h"
#include "Kalman.h"
/* USER CODE END Includes */

/* USER CODE BEGIN PTD */
typedef enum {
	FLY_MODE_OFF = 0b0001, FLY_MODE_ON = 0b0011, FLY_MODE_HOLD = 0b0111
} FLY_MODE_t;

typedef enum {
	LANDING_MODE_MANUAL = 0b0001, LANDING_MODE_AUTO = 0b0011
} LANDING_MODE_t;
/* USER CODE END PTD */

/* USER CODE BEGIN PD */
#define MainBuf_SIZE 256
#define RxBuf_SIZE 128
#define SERIAL_DEBUG huart2
/* USER CODE END PD */

ADC_HandleTypeDef hadc1;

I2C_HandleTypeDef hi2c1;

SD_HandleTypeDef hsd;

SPI_HandleTypeDef hspi1;
SPI_HandleTypeDef hspi2;

TIM_HandleTypeDef htim2;
TIM_HandleTypeDef htim3;
TIM_HandleTypeDef htim4;
TIM_HandleTypeDef htim5;
TIM_HandleTypeDef htim6;
TIM_HandleTypeDef htim9;
TIM_HandleTypeDef htim10;
TIM_HandleTypeDef htim11;
TIM_HandleTypeDef htim12;

UART_HandleTypeDef huart4;
UART_HandleTypeDef huart1;
UART_HandleTypeDef huart2;
UART_HandleTypeDef huart3;
DMA_HandleTypeDef hdma_usart2_rx;

/* Definitions for IMU_Task */
osThreadId_t IMU_TaskHandle;
const osThreadAttr_t IMU_Task_attributes = {
  .name = "IMU_Task",
  .stack_size = 512 * 4,
  .priority = (osPriority_t) osPriorityRealtime,
};
/* Definitions for Remote_Task */
osThreadId_t Remote_TaskHandle;
const osThreadAttr_t Remote_Task_attributes = {
  .name = "Remote_Task",
  .stack_size = 512 * 4,
  .priority = (osPriority_t) osPriorityNormal3,
};
/* Definitions for PrintSerial_Tas */
osThreadId_t PrintSerial_TasHandle;
const osThreadAttr_t PrintSerial_Tas_attributes = {
  .name = "PrintSerial_Tas",
  .stack_size = 512 * 4,
  .priority = (osPriority_t) osPriorityNormal,
};
/* Definitions for BMP_Task */
osThreadId_t BMP_TaskHandle;
const osThreadAttr_t BMP_Task_attributes = {
  .name = "BMP_Task",
  .stack_size = 512 * 4,
  .priority = (osPriority_t) osPriorityLow,
};
/* Definitions for Task_Controller */
osThreadId_t Task_ControllerHandle;
const osThreadAttr_t Task_Controller_attributes = {
  .name = "Task_Controller",
  .stack_size = 512 * 4,
  .priority = (osPriority_t) osPriorityRealtime1,
};
/* Definitions for SerialRecv_Task */
osThreadId_t SerialRecv_TaskHandle;
const osThreadAttr_t SerialRecv_Task_attributes = {
  .name = "SerialRecv_Task",
  .stack_size = 512 * 4,
  .priority = (osPriority_t) osPriorityNormal,
};
/* Definitions for SPI1_Mutex */
osMutexId_t SPI1_MutexHandle;
const osMutexAttr_t SPI1_Mutex_attributes = {
  .name = "SPI1_Mutex"
};
/* Definitions for SerialDebug_Mutex */
osMutexId_t SerialDebug_MutexHandle;
const osMutexAttr_t SerialDebug_Mutex_attributes = {
  .name = "SerialDebug_Mutex"
};
/* Definitions for Fly_Event */
osEventFlagsId_t Fly_EventHandle;
const osEventFlagsAttr_t Fly_Event_attributes = {
  .name = "Fly_Event"
};
/* Definitions for Landing_Event */
osEventFlagsId_t Landing_EventHandle;
const osEventFlagsAttr_t Landing_Event_attributes = {
  .name = "Landing_Event"
};
/* Definitions for Calibration_Event */
osEventFlagsId_t Calibration_EventHandle;
const osEventFlagsAttr_t Calibration_Event_attributes = {
  .name = "Calibration_Event"
};
/* USER CODE BEGIN PV */
//Serial
uint8_t strBuffer[512];
uint16_t strSize = 0;
uint16_t USART2Length = 0;

//IMU
float MPU9250_selfTest[6];
MPU9250_t mpu9250;
float accX, accY, accZ;
float magX, magY, magZ;
float gyrX, gyrY, gyrZ;
float IMURateFreq = 0;
float quaternion[4];
float IMU_delta;
bool updateIMU = false;
bool updateRemote = true;
FusionAhrs fusionahrs;
uint32_t IMU_cntNow = 0;
uint32_t IMU_cntPrev = 0;
FusionVector3 accel;
FusionVector3 gyro;
FusionVector3 magnet;
static FusionEulerAngles eulerPV;
static FusionEulerAngles eulerCalibration;
float tmpRoll = 0.0;
FusionBias fusionBias;
FusionEulerAngles eulerPVArray[12];
uint8_t eulerPVCount = 0;
uint32_t eulerPVSampling = 5;
float pid_ts = 0.005;

HAL_StatusTypeDef halStatusTypeDef;

//Position
FusionVector3 linearAccel;
FusionVector3 linearVelocity;
FusionVector3 linearPosition;

//BMP280
struct bmp2_status bmp_status;
struct bmp2_data bmp_comp_data;
struct bmp2_dev bmp_dev;
struct bmp2_config bmp_conf, bmp_test;
int8_t bmp_rslt = BMP2_E_NULL_PTR;
float bmp_delta;
uint32_t bmp_cntNow = 0;
uint32_t bmp_cntPrev = 0;
float bmpRateFreq = 0;
double altitude = 0.0;
double estimated_altitude = 0.0;

//Remote
RC_t PPMRC;
volatile uint32_t PPMOutput[9];
uint32_t Fly_Mode_Flag = FLY_MODE_OFF;
uint32_t Landing_Mode_Flag = LANDING_MODE_MANUAL;

//Position Controller
volatile Velocity_t inputVel;

//MODE
FLY_MODE_t fly_mode = FLY_MODE_OFF;
LANDING_MODE_t flight_mode = LANDING_MODE_MANUAL;

//Control
PIDType_t PIDPitch, PIDRoll, PIDYaw;

extern float G;
/* USER CODE END PV */

void SystemClock_Config(void);
static void MX_GPIO_Init(void);
static void MX_I2C1_Init(void);
static void MX_SDIO_SD_Init(void);
static void MX_SPI1_Init(void);
static void MX_SPI2_Init(void);
static void MX_TIM5_Init(void);
static void MX_TIM9_Init(void);
static void MX_TIM10_Init(void);
static void MX_TIM11_Init(void);
static void MX_UART4_Init(void);
static void MX_USART1_UART_Init(void);
static void MX_USART2_UART_Init(void);
static void MX_USART3_UART_Init(void);
static void MX_ADC1_Init(void);
static void MX_TIM2_Init(void);
static void MX_TIM6_Init(void);
static void MX_TIM12_Init(void);
static void MX_TIM3_Init(void);
static void MX_DMA_Init(void);
static void MX_TIM4_Init(void);
void Start_IMU_Task(void *argument);
void Start_Remote_Task(void *argument);
void Start_PrintSerial_Task(void *argument);
void Start_BMP_Task(void *argument);
void Start_Task_Controller(void *argument);
void Start_SerialReceive_Task(void *argument);

static void MX_NVIC_Init(void);
/* USER CODE BEGIN 0 */
uint32_t DWT_Init(void) {
	/* Disable TRC */
	CoreDebug->DEMCR &= ~CoreDebug_DEMCR_TRCENA_Msk; // ~0x01000000;
	/* Enable TRC */
	CoreDebug->DEMCR |= CoreDebug_DEMCR_TRCENA_Msk; // 0x01000000;
	/* Disable clock cycle counter */
	DWT->CTRL &= ~DWT_CTRL_CYCCNTENA_Msk; //~0x00000001;
	/* Enable  clock cycle counter */
	DWT->CTRL |= DWT_CTRL_CYCCNTENA_Msk; //0x00000001;
	/* Reset the clock cycle counter value */
	DWT->CYCCNT = 0;
	/* 3 NO OPERATION instructions */
	__ASM volatile ("NOP");
	__ASM volatile ("NOP");
	__ASM volatile ("NOP");
	/* Check if clock cycle counter has started */
	if (DWT->CYCCNT) {
		return 0; /*clock cycle counter started*/
	} else {
		return 1; /*clock cycle counter not started*/
	}
}

__STATIC_INLINE uint32_t DWT_GetuS() {
	return DWT->CYCCNT / (SystemCoreClock / 1000000U);
}

static int8_t get_data(uint32_t period, struct bmp2_config *conf,
		struct bmp2_dev *dev) {
	int8_t rslt = BMP2_E_NULL_PTR;
	int8_t idx = 1;
	struct bmp2_status status;
	struct bmp2_data comp_data;

	printf("Measurement delay : %lu us\r\n", (long unsigned int) period);

	while (idx <= 50) {
		rslt = bmp2_get_status(&status, dev);
		bmp2_error_codes_print_result("bmp2_get_status", rslt);

		if (status.measuring == BMP2_MEAS_DONE) {
			/* Delay between measurements */
			dev->delay_us(period, dev->intf_ptr);

			/* Read compensated data */
			rslt = bmp2_get_sensor_data(&comp_data, dev);
			bmp2_error_codes_print_result("bmp2_get_sensor_data", rslt);

#ifdef BMP2_64BIT_COMPENSATION
            comp_data.pressure = comp_data.pressure / 256;
            #endif

#ifdef BMP2_DOUBLE_COMPENSATION
			printf("Data[%d]:    Temperature: %f deg C	Pressure: %f Pa\r\n",
					idx, comp_data.temperature, comp_data.pressure);
#else
            printf("Data[%d]:    Temperature: %ld deg C	Pressure: %lu Pa\n", idx, (long int)comp_data.temperature,
                   (long unsigned int)comp_data.pressure);
            #endif

			idx++;
		}
	}

	return rslt;
}

void bmp280_setup(struct bmp2_config *conf, struct bmp2_dev *dev) {

}

void accelerometer_calibration_orientation(MPU9250_t *mpu9250,
		Orientation orientation) {
	switch (orientation) {
	case Front:
		while (mpu9250->_ax <= 1.0f * G) {
			MPU9250_readSensor(mpu9250);
			HAL_Delay(5);
		}
		HAL_Delay(1500);
		printf("Mengambil Data xmax\r\n");
		break;
	case Back:
		while (mpu9250->_ax >= -1.0f * G) {
			MPU9250_readSensor(mpu9250);
			HAL_Delay(5);
		}
		HAL_Delay(1500);
		printf("Mengambil Data xmin\r\n");
		break;
	case Left:
		while (mpu9250->_ay >= -1.0f * G) {
			MPU9250_readSensor(mpu9250);
			HAL_Delay(5);
		}
		HAL_Delay(1500);
		printf("Mengambil Data ymin\r\n");
		break;
	case Right:
		while (mpu9250->_ay <= 1.0f * G) {
			MPU9250_readSensor(mpu9250);
			HAL_Delay(5);
		}
		HAL_Delay(1500);
		printf("Mengambil Data ymax\r\n");
		break;
	case Top:
		while (mpu9250->_az >= -1.0f * G) {
			MPU9250_readSensor(mpu9250);
			HAL_Delay(5);
		}
		HAL_Delay(1500);
		printf("Mengambil Data zmin\r\n");
		break;
	case Bottom:
		while (!(mpu9250->_az >= 0.82) && mpu9250->_az <= 1.0f * G) {
			MPU9250_readSensor(mpu9250);
			HAL_Delay(5);
		}
		HAL_Delay(1500);
		printf("Mengambil Data zmax\r\n");
		break;
	default:
		break;
	}

	switch (orientation) {
	case Front:
	case Back:
		mpu9250->_axbD = 0;
		for (int i = 0; i < mpu9250->_numSamples; i++) {
			MPU9250_readSensor(mpu9250);
			mpu9250->_axbD += mpu9250->_ax;
			HAL_Delay(20);
		}
		break;

	case Left:
	case Right:
		mpu9250->_aybD = 0;
		for (int i = 0; i < mpu9250->_numSamples; i++) {
			MPU9250_readSensor(mpu9250);
			mpu9250->_aybD += mpu9250->_ay;
			HAL_Delay(20);
		}
		break;

	case Top:
	case Bottom:
		mpu9250->_azbD = 0;
		for (int i = 0; i < mpu9250->_numSamples; i++) {
			MPU9250_readSensor(mpu9250);
			mpu9250->_azbD += mpu9250->_az;
			HAL_Delay(20);
		}
		break;
	default:
		break;
	}
}

void accelerometer_calibration(MPU9250_t *mpu9250) {

	if (MPU9250_setAccelRange(mpu9250, ACCEL_RANGE_2G) < 0) {
		printf("Error\r\n");
	}
	if (MPU9250_setDlpfBandwidth(mpu9250, DLPF_BANDWIDTH_20HZ) < 0) {
		printf("Error\r\n");
	}
	if (MPU9250_setSrd(mpu9250, 19) < 0) {
		printf("Error\r\n");
	}

	for (int i = 0; i < 100; i++) {
		MPU9250_readSensor(mpu9250);
		HAL_Delay(5);
	}

	printf("Posisikan menghadap ke atas!\r\n");
	accelerometer_calibration_orientation(mpu9250, Top);

	mpu9250->_azmin = mpu9250->_azbD / mpu9250->_numSamples;
	printf("zmin: %f\r\n", mpu9250->_azmin);

	printf("Posisikan menghadap ke depan!\r\n");
	accelerometer_calibration_orientation(mpu9250, Front);

	mpu9250->_axmax = mpu9250->_axbD / mpu9250->_numSamples;
	printf("xmax: %f\r\n", mpu9250->_axmax);

	printf("Posisikan menghadap ke kiri!\r\n");
	accelerometer_calibration_orientation(mpu9250, Left);

	mpu9250->_aymin = mpu9250->_aybD / mpu9250->_numSamples;
	printf("ymin: %f\r\n", mpu9250->_aymin);

	printf("Posisikan menghadap ke belakang!\r\n");
	accelerometer_calibration_orientation(mpu9250, Back);

	mpu9250->_axmin = mpu9250->_axbD / mpu9250->_numSamples;
	printf("xmin: %f\r\n", mpu9250->_axmin);

	printf("Posisikan menghadap ke kanan!\r\n");
	accelerometer_calibration_orientation(mpu9250, Right);

	mpu9250->_aymax = mpu9250->_aybD / mpu9250->_numSamples;
	printf("ymax: %f\r\n", mpu9250->_aymax);

	printf("Posisikan menghadap ke bawah!\r\n");
	accelerometer_calibration_orientation(mpu9250, Bottom);

	mpu9250->_azmax = mpu9250->_azbD / mpu9250->_numSamples;
	printf("zmax: %f\r\n", mpu9250->_azmax);

	// set the range, bandwidth, and srd back to what they were
	if (MPU9250_setAccelRange(mpu9250, mpu9250->_accelRange) < 0) {
		printf("Error!\r\n");
	}
	if (MPU9250_setDlpfBandwidth(mpu9250, mpu9250->_bandwidth) < 0) {
		printf("Error!\r\n");
	}
	if (MPU9250_setSrd(mpu9250, mpu9250->_srd) < 0) {
		printf("Error!\r\n");
	}

	mpu9250->_axb = (mpu9250->_axmin + mpu9250->_axmax) / 2.0f;
	mpu9250->_axs = G / ((fabs(mpu9250->_axmin) + fabs(mpu9250->_axmax)) / 2.0f);

	mpu9250->_ayb = (mpu9250->_aymin + mpu9250->_aymax) / 2.0f;
	mpu9250->_ays = G / ((fabs(mpu9250->_aymin) + fabs(mpu9250->_aymax)) / 2.0f);

	mpu9250->_azb = (mpu9250->_azmin + mpu9250->_azmax) / 2.0f;
	mpu9250->_azs = G / ((fabs(mpu9250->_azmin) + fabs(mpu9250->_azmax)) / 2.0f);

	printf("axb: %f\taxs: %f\r\n", mpu9250->_axb, mpu9250->_axs);
	printf("ayb: %f\tays: %f\r\n", mpu9250->_ayb, mpu9250->_ays);
	printf("azb: %f\tazs: %f\r\n", mpu9250->_azb, mpu9250->_azs);

	HAL_Delay(3000);
}

static void PIDReset(PIDType_t *pidtype) {
	pidtype->sumIntegral = 0;
	pidtype->output = 0;

	TIM10->CCR1 = 1000;
	TIM2->CCR2 = 1000;
	TIM2->CCR3 = 1000;
	TIM2->CCR4 = 1000;
}

static void PIDInit(PIDType_t *pidtype, double kp, double ki, double kd,
		double timesampling) {
	PIDReset(pidtype);

	pidtype->kp = kp;
	pidtype->kd = kd;
	pidtype->ki = ki;

	pidtype->timesampling = timesampling;
}

static void PIDControl(PIDType_t *pidtype, float dataSensor, float setPoint) {
	pidtype->setPoint = constrain(setPoint, -30.0, 30.0);
	pidtype->error = pidtype->setPoint - dataSensor;

	if (pidtype->error >= 180.0)
		pidtype->error -= 360.0;
	else if (pidtype->error < -180.0)
		pidtype->error += 360.0;

	pidtype->sumIntegral += pidtype->error * pidtype->timesampling;
	pidtype->sumIntegral = constrain(pidtype->sumIntegral, -500.0, 500.0);

	pidtype->derivative = (pidtype->error - pidtype->preverror)
			/ pidtype->timesampling;
	pidtype->preverror = pidtype->error;

	pidtype->output = (pidtype->kp * pidtype->error)
			+ (pidtype->kd * pidtype->derivative)
			+ (pidtype->ki * pidtype->sumIntegral);
}

void OrientationUpdate() {
	osThreadFlagsWait(0x1, osFlagsWaitAny, osWaitForever);

	accX = MPU9250_getAccelX_g(&mpu9250);
	accY = MPU9250_getAccelY_g(&mpu9250);
	accZ = MPU9250_getAccelZ_g(&mpu9250);

	gyrX = MPU9250_getGyroX_rads(&mpu9250);
	gyrY = MPU9250_getGyroY_rads(&mpu9250);
	gyrZ = MPU9250_getGyroZ_rads(&mpu9250);

	magX = MPU9250_getMagX_uT(&mpu9250);
	magY = MPU9250_getMagY_uT(&mpu9250);
	magZ = MPU9250_getMagZ_uT(&mpu9250);

	accel.axis.x = accX;
	accel.axis.y = accY;
	accel.axis.z = accZ;

	gyro.axis.x = gyrX * RAD_TO_DEG;
	gyro.axis.y = gyrY * RAD_TO_DEG;
	gyro.axis.z = gyrZ * RAD_TO_DEG;

	magnet.axis.x = magX;
	magnet.axis.y = magY;
	magnet.axis.z = magZ;

	FusionBiasUpdate(&fusionBias, gyro);

	FusionAhrsUpdate(&fusionahrs, gyro, accel, magnet, IMU_delta);
	eulerPV = FusionQuaternionToEulerAngles(
			FusionAhrsGetQuaternion(&fusionahrs));

	eulerPV.angle.pitch = (-1.0 * eulerPV.angle.pitch);
	//eulerPV.angle.roll = -1.0 * eulerPV.angle.roll;

	if (eulerPV.angle.roll < 180.0 && eulerPV.angle.roll >= 0) {
		eulerPV.angle.roll = map(eulerPV.angle.roll, 0.0, 180.0, -180.0, 0.0);
	} else if (eulerPV.angle.roll > -180.0 && eulerPV.angle.roll <= 0.0) {
		eulerPV.angle.roll = map(eulerPV.angle.roll, -180.0, 0.0, 0.0, 180.0);
	}

	eulerPV.angle.roll -= eulerCalibration.angle.roll;
	eulerPV.angle.pitch -= eulerCalibration.angle.pitch;
	eulerPV.angle.yaw -= eulerCalibration.angle.yaw;

	//osThreadFlagsClear(0x1);
}

void OrientationCalibrationUpdate() {
	eulerCalibration.angle.roll = 0.0f;
	eulerCalibration.angle.pitch = 0.0f;
	eulerCalibration.angle.yaw = 0.0f;

	FusionEulerAngles eulerTotal;

	for (int i = 0; i < 1000; i++) {
		//osThreadFlagsWait(0x1, osFlagsWaitAny, osWaitForever);

		OrientationUpdate();

		eulerTotal.angle.roll += eulerPV.angle.roll;
		eulerTotal.angle.pitch += eulerPV.angle.pitch;
		eulerTotal.angle.yaw += eulerPV.angle.yaw;

		//osThreadFlagsClear(0x1);
	}
	eulerCalibration.angle.roll = eulerTotal.angle.roll / 1000.0;
	eulerCalibration.angle.pitch = eulerTotal.angle.pitch / 1000.0;
	eulerCalibration.angle.yaw = eulerTotal.angle.yaw / 1000.0;
}

/* USER CODE END 0 */

/**
  * @brief  The application entry point.
  * @retval int
  */
int main(void)
{
  /* MCU Configuration--------------------------------------------------------*/

  /* Reset of all peripherals, Initializes the Flash interface and the Systick. */
  HAL_Init();

  /* Configure the system clock */
  SystemClock_Config();

  /* Initialize all configured peripherals */
  MX_GPIO_Init();
  MX_I2C1_Init();
  MX_SDIO_SD_Init();
  MX_SPI1_Init();
  MX_SPI2_Init();
  MX_TIM5_Init();
  MX_TIM9_Init();
  MX_TIM10_Init();
  MX_TIM11_Init();
  MX_UART4_Init();
  MX_USART1_UART_Init();
  MX_DMA_Init();
  MX_USART2_UART_Init();
  MX_USART3_UART_Init();
  MX_ADC1_Init();
  MX_TIM2_Init();
  MX_TIM6_Init();
  MX_TIM12_Init();
  MX_FATFS_Init();
  MX_TIM3_Init();
  MX_TIM4_Init();

  /* Initialize interrupts */
  MX_NVIC_Init();
  /* USER CODE BEGIN 2 */
	HAL_TIM_PWM_Start(&htim2, TIM_CHANNEL_2);
	HAL_TIM_PWM_Start(&htim2, TIM_CHANNEL_3);
	HAL_TIM_PWM_Start(&htim2, TIM_CHANNEL_4);
	HAL_TIM_PWM_Start(&htim10, TIM_CHANNEL_1);

	HAL_Delay(100);
	RetargetInit(&SERIAL_DEBUG);

	printf("Coba printf\r\n");

	printf("Mulai!\r\n");

	if (DWT_Init()) {
		printf("DWT gagal inisialisasi!\r\n");
		while (1)
			;
	}

	/*HAL_TIM_PWM_Start(&htim11, TIM_CHANNEL_1);
	 TIM11->CCR1 = 500;
	 HAL_Delay(3000);
	 TIM11->CCR1 = 0;*/

	//MPU9250_begin();
	/*uint8_t imu_whoami = MPU9250_WhoAmI();

	 strSize = sprintf((char*)strBuffer, "Hasil Who Am I MPU9250: %d\r\n", imu_whoami);
	 HAL_UART_Transmit(&SERIAL_DEBUG, strBuffer, strSize, HAL_MAX_DELAY);

	 if(imu_whoami != 0x71 && imu_whoami != 0x73){
	 strSize = sprintf((char*)strBuffer, "Gagal inisialiasasi IMU!\r\n");
	 HAL_UART_Transmit(&SERIAL_DEBUG, strBuffer, strSize, HAL_MAX_DELAY);
	 while(1);
	 } else {
	 MPU9250_SelfTest(MPU9250_selfTest);

	 strSize = sprintf((char*)strBuffer, "x-Axis self test: acceleration trim within: %f %% of factory value\r\n", MPU9250_selfTest[0]);
	 HAL_UART_Transmit(&SERIAL_DEBUG, strBuffer, strSize, HAL_MAX_DELAY);

	 strSize = sprintf((char*)strBuffer, "y-Axis self test: acceleration trim within: %f %% of factory value\r\n", MPU9250_selfTest[1]);
	 HAL_UART_Transmit(&SERIAL_DEBUG, strBuffer, strSize, HAL_MAX_DELAY);

	 strSize = sprintf((char*)strBuffer, "z-Axis self test: acceleration trim within: %f %% of factory value\r\n", MPU9250_selfTest[2]);
	 HAL_UART_Transmit(&SERIAL_DEBUG, strBuffer, strSize, HAL_MAX_DELAY);

	 strSize = sprintf((char*)strBuffer, "x-Axis self test: gyration trim within: %f %% of factory value\r\n", MPU9250_selfTest[3]);
	 HAL_UART_Transmit(&SERIAL_DEBUG, strBuffer, strSize, HAL_MAX_DELAY);

	 strSize = sprintf((char*)strBuffer, "y-Axis self test: gyration trim within: %f %% of factory value\r\n", MPU9250_selfTest[4]);
	 HAL_UART_Transmit(&SERIAL_DEBUG, strBuffer, strSize, HAL_MAX_DELAY);

	 strSize = sprintf((char*)strBuffer, "z-Axis self test: gyration trim within: %f %% of factory value\r\n", MPU9250_selfTest[5]);
	 HAL_UART_Transmit(&SERIAL_DEBUG, strBuffer, strSize, HAL_MAX_DELAY);
	 }

	 uint8_t magnet_whoami = MPU9250_AK8963WhoAmI();

	 strSize = sprintf((char*)strBuffer, "Hasil Who Am I AK8963: %d\r\n", magnet_whoami);
	 HAL_UART_Transmit(&SERIAL_DEBUG, strBuffer, strSize, HAL_MAX_DELAY);

	 if(magnet_whoami != 0x48){
	 strSize = sprintf((char*)strBuffer, "Gagal inisialiasasi Magnetometer!\r\n");
	 HAL_UART_Transmit(&SERIAL_DEBUG, strBuffer, strSize, HAL_MAX_DELAY);
	 while(1);
	 }*/
  /* USER CODE END 2 */

  /* Init scheduler */
  osKernelInitialize();
  /* Create the mutex(es) */
  /* creation of SPI1_Mutex */
  SPI1_MutexHandle = osMutexNew(&SPI1_Mutex_attributes);

  /* creation of SerialDebug_Mutex */
  SerialDebug_MutexHandle = osMutexNew(&SerialDebug_Mutex_attributes);

  /* USER CODE BEGIN RTOS_MUTEX */
	/* add mutexes, ... */
  /* USER CODE END RTOS_MUTEX */

  /* USER CODE BEGIN RTOS_SEMAPHORES */
	/* add semaphores, ... */
  /* USER CODE END RTOS_SEMAPHORES */

  /* USER CODE BEGIN RTOS_TIMERS */
	/* start timers, add new ones, ... */
  /* USER CODE END RTOS_TIMERS */

  /* USER CODE BEGIN RTOS_QUEUES */
	/* add queues, ... */
  /* USER CODE END RTOS_QUEUES */

  /* Create the thread(s) */
  /* creation of IMU_Task */
  IMU_TaskHandle = osThreadNew(Start_IMU_Task, NULL, &IMU_Task_attributes);

  /* creation of Remote_Task */
  Remote_TaskHandle = osThreadNew(Start_Remote_Task, NULL, &Remote_Task_attributes);

  /* creation of PrintSerial_Tas */
  PrintSerial_TasHandle = osThreadNew(Start_PrintSerial_Task, NULL, &PrintSerial_Tas_attributes);

  /* creation of BMP_Task */
  BMP_TaskHandle = osThreadNew(Start_BMP_Task, NULL, &BMP_Task_attributes);

  /* creation of Task_Controller */
  Task_ControllerHandle = osThreadNew(Start_Task_Controller, NULL, &Task_Controller_attributes);

  /* creation of SerialRecv_Task */
  SerialRecv_TaskHandle = osThreadNew(Start_SerialReceive_Task, NULL, &SerialRecv_Task_attributes);

  /* USER CODE BEGIN RTOS_THREADS */
	/* add threads, ... */
  /* USER CODE END RTOS_THREADS */

  /* creation of Fly_Event */
  Fly_EventHandle = osEventFlagsNew(&Fly_Event_attributes);

  /* creation of Landing_Event */
  Landing_EventHandle = osEventFlagsNew(&Landing_Event_attributes);

  /* creation of Calibration_Event */
  Calibration_EventHandle = osEventFlagsNew(&Calibration_Event_attributes);

  /* USER CODE BEGIN RTOS_EVENTS */
	/* add events, ... */
  /* USER CODE END RTOS_EVENTS */

  /* Start scheduler */
  osKernelStart();

  /* We should never get here as control is now taken by the scheduler */
  /* Infinite loop */
  /* USER CODE BEGIN WHILE */
	while (1) {

    /* USER CODE END WHILE */

    /* USER CODE BEGIN 3 */
	}
  /* USER CODE END 3 */
}

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
/* USER CODE BEGIN 4 */
void HAL_UARTEx_RxEventCallback(UART_HandleTypeDef *huart, uint16_t Size) {
	if (huart->Instance == USART2) {
		osThreadFlagsSet(SerialRecv_TaskHandle, 0x1);
		USART2Length = Size;
	}
}
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

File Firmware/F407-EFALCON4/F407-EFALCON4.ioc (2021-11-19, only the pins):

Mcu.UserName=STM32F407VGTx
PA0-WKUP.GPIO_Label=SBUS_RX
PA0-WKUP.Signal=UART4_TX
PA1.GPIO_Label=PWM_OUT5
PA1.Signal=S_TIM5_CH2
PA10.GPIO_Label=GPS_RX
PA10.Signal=USART1_RX
PA11.GPIO_Label=GPS_INT
PA11.Signal=GPXTI11
PA13.Signal=SYS_JTMS-SWDIO
PA14.Signal=SYS_JTCK-SWCLK
PA15.GPIO_Label=PWM_OUT1
PA15.Signal=S_TIM2_CH1_ETR
PA2.GPIO_Label=PWM_OUT6
PA2.Signal=S_TIM5_CH3
PA3.GPIO_Label=PWM_OUT7
PA3.Signal=S_TIM5_CH4
PA4.GPIO_Label=ADC_BATERAI2
PA4.Signal=ADCx_IN4
PA5.GPIO_Label=IMU_SCK
PA5.Signal=SPI1_SCK
PA6.GPIO_Label=IMU_MISO
PA6.Signal=SPI1_MISO
PA7.GPIO_Label=IMU_MOSI
PA7.Signal=SPI1_MOSI
PA9.GPIO_Label=GPS_TX
PA9.Signal=USART1_TX
PB0.GPIO_Label=REMOTE_CH3
PB0.Signal=S_TIM3_CH3
PB1.GPIO_Label=ADC_BATERAI1
PB1.Signal=ADCx_IN9
PB10.GPIO_Label=PWM_OUT3
PB10.Signal=S_TIM2_CH3
PB11.GPIO_Label=PWM_OUT4
PB11.Signal=S_TIM2_CH4
PB12.GPIO_Label=LORA_DIO1
PB12.Signal=GPIO_Output
PB13.Signal=SPI2_SCK
PB14.GPIO_Label=REMOTE_PPM
PB14.Signal=S_TIM12_CH1
PB15.Signal=GPIO_Output
PB3.GPIO_Label=PWM_OUT2
PB3.Signal=S_TIM2_CH2
PB4.GPIO_Label=REMOTE_CH1
PB4.Signal=S_TIM3_CH1
PB5.GPIO_Label=REMOTE_CH2
PB5.Signal=S_TIM3_CH2
PB6.Signal=I2C1_SCL
PB7.Signal=I2C1_SDA
PB8.GPIO_Label=PWM_OUT8
PB8.Signal=S_TIM10_CH1
PB9.GPIO_Label=PWM_BUZZER
PB9.Signal=S_TIM11_CH1
PC0.GPIO_Label=ADC_ANGIN2
PC0.Signal=ADCx_IN10
PC1.GPIO_Label=ADC_BATERAI3
PC1.Signal=ADCx_IN11
PC10.Signal=SDIO_D2
PC11.Signal=SDIO_D3
PC12.Signal=SDIO_CK
PC13-ANTI_TAMP.GPIO_Label=LORA_NSS
PC13-ANTI_TAMP.Signal=GPIO_Output
PC2.GPIO_Label=LORA_MISO
PC2.Signal=SPI2_MISO
PC3.GPIO_Label=LORA_MOSI
PC3.Signal=SPI2_MOSI
PC4.GPIO_Label=ADC_ANGIN1
PC4.Signal=ADCx_IN14
PC5.GPIO_Label=IMU_CS
PC5.Signal=GPIO_Output
PC8.Signal=SDIO_D0
PC9.Signal=SDIO_D1
PD10.GPIO_Label=LORA_DIO2
PD10.Signal=GPIO_Output
PD11.GPIO_Label=LORA_DIO3
PD11.Signal=GPIO_Output
PD12.GPIO_Label=REMOTE_CH4
PD12.Signal=S_TIM4_CH1
PD13.GPIO_Label=REMOTE_CH5
PD13.Signal=S_TIM4_CH2
PD14.GPIO_Label=REMOTE_CH6
PD14.Signal=S_TIM4_CH3
PD2.Signal=SDIO_CMD
PD5.Signal=USART2_TX
PD6.Signal=USART2_RX
PD8.Signal=USART3_TX
PD9.Signal=USART3_RX
PE1.GPIO_Label=RTC_NC
PE1.Signal=GPIO_Output
PE10.GPIO_Label=LED1
PE10.Signal=GPIO_Output
PE11.GPIO_Label=LED2
PE11.Signal=GPIO_Output
PE12.GPIO_Label=LED3
PE12.Signal=GPIO_Output
PE2.GPIO_Label=US_TRIG
PE2.Signal=GPIO_Output
PE3.Signal=GPIO_Output
PE4.Signal=GPIO_Output
PE5.GPIO_Label=US_ECHO
PE5.Signal=S_TIM9_CH1
PE6.GPIO_Label=LORA_RST
PE6.Signal=GPIO_Output
PE7.GPIO_Label=BMP_CS
PE7.Signal=GPIO_Output
PH0-OSC_IN.Signal=RCC_OSC_IN
PH1-OSC_OUT.Signal=RCC_OSC_OUT

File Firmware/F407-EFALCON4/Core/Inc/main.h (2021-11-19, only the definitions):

#define US_TRIG_Pin GPIO_PIN_2
#define US_TRIG_GPIO_Port GPIOE
#define US_ECHO_Pin GPIO_PIN_5
#define US_ECHO_GPIO_Port GPIOE
#define LORA_RST_Pin GPIO_PIN_6
#define LORA_RST_GPIO_Port GPIOE
#define LORA_NSS_Pin GPIO_PIN_13
#define LORA_NSS_GPIO_Port GPIOC
#define ADC_ANGIN2_Pin GPIO_PIN_0
#define ADC_ANGIN2_GPIO_Port GPIOC
#define ADC_BATERAI3_Pin GPIO_PIN_1
#define ADC_BATERAI3_GPIO_Port GPIOC
#define LORA_MISO_Pin GPIO_PIN_2
#define LORA_MISO_GPIO_Port GPIOC
#define LORA_MOSI_Pin GPIO_PIN_3
#define LORA_MOSI_GPIO_Port GPIOC
#define SBUS_RX_Pin GPIO_PIN_0
#define SBUS_RX_GPIO_Port GPIOA
#define PWM_OUT5_Pin GPIO_PIN_1
#define PWM_OUT5_GPIO_Port GPIOA
#define PWM_OUT6_Pin GPIO_PIN_2
#define PWM_OUT6_GPIO_Port GPIOA
#define PWM_OUT7_Pin GPIO_PIN_3
#define PWM_OUT7_GPIO_Port GPIOA
#define ADC_BATERAI2_Pin GPIO_PIN_4
#define ADC_BATERAI2_GPIO_Port GPIOA
#define IMU_SCK_Pin GPIO_PIN_5
#define IMU_SCK_GPIO_Port GPIOA
#define IMU_MISO_Pin GPIO_PIN_6
#define IMU_MISO_GPIO_Port GPIOA
#define IMU_MOSI_Pin GPIO_PIN_7
#define IMU_MOSI_GPIO_Port GPIOA
#define ADC_ANGIN1_Pin GPIO_PIN_4
#define ADC_ANGIN1_GPIO_Port GPIOC
#define IMU_CS_Pin GPIO_PIN_5
#define IMU_CS_GPIO_Port GPIOC
#define REMOTE_CH3_Pin GPIO_PIN_0
#define REMOTE_CH3_GPIO_Port GPIOB
#define ADC_BATERAI1_Pin GPIO_PIN_1
#define ADC_BATERAI1_GPIO_Port GPIOB
#define BMP_CS_Pin GPIO_PIN_7
#define BMP_CS_GPIO_Port GPIOE
#define LED1_Pin GPIO_PIN_10
#define LED1_GPIO_Port GPIOE
#define LED2_Pin GPIO_PIN_11
#define LED2_GPIO_Port GPIOE
#define LED3_Pin GPIO_PIN_12
#define LED3_GPIO_Port GPIOE
#define PWM_OUT3_Pin GPIO_PIN_10
#define PWM_OUT3_GPIO_Port GPIOB
#define PWM_OUT4_Pin GPIO_PIN_11
#define PWM_OUT4_GPIO_Port GPIOB
#define LORA_DIO1_Pin GPIO_PIN_12
#define LORA_DIO1_GPIO_Port GPIOB
#define REMOTE_PPM_Pin GPIO_PIN_14
#define REMOTE_PPM_GPIO_Port GPIOB
#define LORA_DIO2_Pin GPIO_PIN_10
#define LORA_DIO2_GPIO_Port GPIOD
#define LORA_DIO3_Pin GPIO_PIN_11
#define LORA_DIO3_GPIO_Port GPIOD
#define REMOTE_CH4_Pin GPIO_PIN_12
#define REMOTE_CH4_GPIO_Port GPIOD
#define REMOTE_CH5_Pin GPIO_PIN_13
#define REMOTE_CH5_GPIO_Port GPIOD
#define REMOTE_CH6_Pin GPIO_PIN_14
#define REMOTE_CH6_GPIO_Port GPIOD
#define GPS_TX_Pin GPIO_PIN_9
#define GPS_TX_GPIO_Port GPIOA
#define GPS_RX_Pin GPIO_PIN_10
#define GPS_RX_GPIO_Port GPIOA
#define GPS_INT_Pin GPIO_PIN_11
#define GPS_INT_GPIO_Port GPIOA
#define PWM_OUT1_Pin GPIO_PIN_15
#define PWM_OUT1_GPIO_Port GPIOA
#define PWM_OUT2_Pin GPIO_PIN_3
#define PWM_OUT2_GPIO_Port GPIOB
#define REMOTE_CH1_Pin GPIO_PIN_4
#define REMOTE_CH1_GPIO_Port GPIOB
#define REMOTE_CH2_Pin GPIO_PIN_5
#define REMOTE_CH2_GPIO_Port GPIOB
#define PWM_OUT8_Pin GPIO_PIN_8
#define PWM_OUT8_GPIO_Port GPIOB
#define PWM_BUZZER_Pin GPIO_PIN_9
#define PWM_BUZZER_GPIO_Port GPIOB
#define RTC_NC_Pin GPIO_PIN_1
#define RTC_NC_GPIO_Port GPIOE

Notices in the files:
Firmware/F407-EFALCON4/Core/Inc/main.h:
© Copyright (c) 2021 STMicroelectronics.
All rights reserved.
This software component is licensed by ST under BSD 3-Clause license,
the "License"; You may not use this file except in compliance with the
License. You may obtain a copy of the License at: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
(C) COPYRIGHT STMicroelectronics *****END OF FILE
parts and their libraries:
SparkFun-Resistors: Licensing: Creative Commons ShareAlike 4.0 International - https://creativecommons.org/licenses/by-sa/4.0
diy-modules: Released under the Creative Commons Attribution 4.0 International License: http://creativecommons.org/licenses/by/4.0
